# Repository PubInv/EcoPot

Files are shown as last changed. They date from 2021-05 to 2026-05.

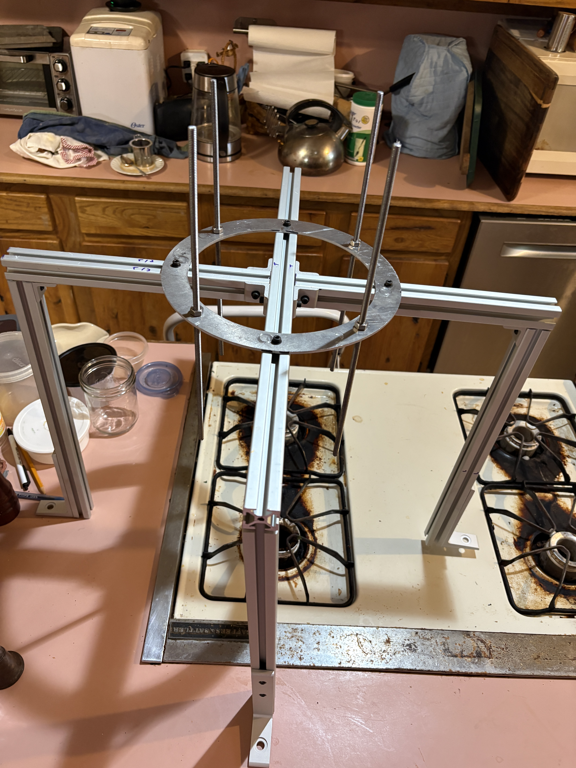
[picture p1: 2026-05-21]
doc/images/test_stand.jpg

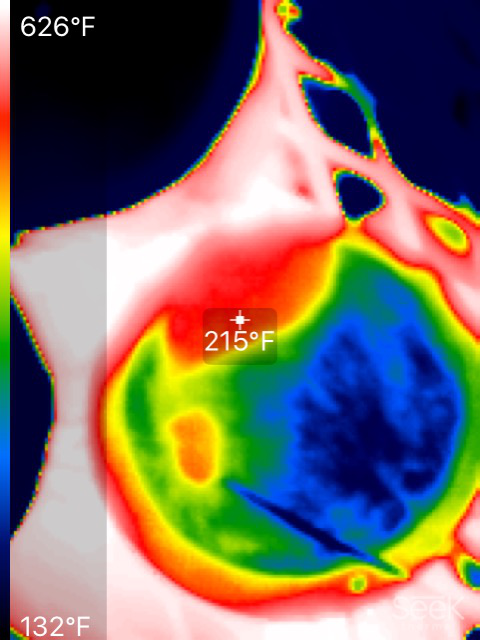
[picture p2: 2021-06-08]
Prototypes and Testing--Rice Team/IR Camera/First test (Open Flame)/IMG_0008.jpg

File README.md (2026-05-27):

# EcoPot
Project #5: A more efficient pot for those who cook over wood fires and related technologies

# Status - May 21st

Gialunuca Skirde had designed and built the a test stand, which we will use for simultaneously testing 4 pots for boiling time. Eventually, we will use this test frame to test over wood fires.

# The "Erlenmeyer" pot design - May 26th

We have not yet tested this pot design but just got it.





# Our Latest, Best Pot design...

These hemispherical, finned pots have been measured with a heat gun to be very efficient!
IMG_1574 (2)
IMG_1575 (2)

# Test with Mini Pot Holder In January

We have used Computational Fluid Dynamics (OpenFOAM) to simulate a number of designs.
Round-bottom parts are better than flat-bottomed pots. Heat transfer fins work.

It remains an open question if we can make a "wavy" pot or a pot like an "Erlenmeyer flask" which is better than our
best pot so far.

We also have a test apparatus for testing minuature 100 ml pots 3D printed in metal (see below).
Our next goal is to 3D print our best pots in metal and test them using this apparatus.






# Status as of September, 2025

We 3D-printed a pot without heat transfer fins in the 100ml size. Using a heat gun strapped
to a pipe, we were able to boil water efficiently. This is not a scientific test; it is a prelude
to A-B testing. Nonetheless, one must sometimes "play" to design the next step.



https://github.com/user-attachments/assets/eb1e9b2b-b452-4a84-bfa1-b5ce4db439bc

We attempted first to use a dryer hose, and that was a complete failure. The heat gun was so hot that 
it discolored the inside of the dryer hose. It is clear that a great deal of heat was lost through
the hose, as the discoloration faded for about 3 feet.



By the way, this small pot (we use 100ml standard test size) boils VERY quickly when put over a natural gas 
burner. We are learning that the temperature of the heating gas is extremely important.

# Status as of June, 2025

Thanks to Cledden Kwanin and Ivan Urdiales, we have a computational fluid dynaimcs (CFD) simulation
based on OpenFOAM. We are approaching the ability to test hypotheses with this tool.

We have a particular design based on an initial hypothesis: The faster the flow around the pot,
the more the flames and hot flue gases will be "sucked" against the pot due to the Coandă effect/Bernoulli 
effect. Based on this idea, we have made a "fish" shaped pot (and lid) which is streamlined,
with heat transfer fins. 

Our initial goal is to compare this pot to a cylindrical pot.






# Team Ecopot for Rice University

Team Ecopot, of Rice University, did the initial work based on ideas from Public Invention.
They are:

1. Christopher J Fang
1. Kaitlyn Wang
1. Stephanie A. Ponce
1. Concepcion C Appio-Riley
1. Sana A. Mohamed
1. Samuel Robedee

# Research Papers (WIP)







"Revisiting the optimal shape of cooling fins: A one-dimensional analytical study using optimality conditions" by
Joe Alexandersen and Ole Sigmund.

[https://arxiv.org/pdf/2012.04310](https://arxiv.org/pdf/2012.04310)

# Volunteer Opportunities

This project is still active, and the team is looking for additional volunteers with varied experience. Currently, the skillsets and experience that are needed include backgrounds in:

* Heat engineering
* Machining/making/3D printing
* Solid modeling/design

Alternatively, if you are new to the technical field but have interest in:

* Performing rigorous experiments, or
* Managing practical finances.

There is also a place for you on the team. If interested in joining the Ecopot or projects like it, reach out to Inventor Coach [Robert L. Read](read.robert@gmail.com) or Volunteer Coordinator [Miriam Castillo](https://www.linkedin.com/in/cstllgtrrz/). Ultimately, our mission is to further the reach of open-source medical engineering, and invent in the public, for the public. Check out our [Volunteer Page](https://www.pubinv.org/volunteer/) to learn more.

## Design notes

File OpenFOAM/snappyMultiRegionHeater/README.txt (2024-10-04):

- To solve the case, run the Allrun_Modified bash script for all the pre-processing. You can also use the Allrun-parallel or Allrun-serial bash scripts to run the case in parallel mode.
- Go to controldict in the system directory and adjust the endTime parameter to a higher (for more simulation time) or lower (for a shorter simulation time).
- Run chtMultiRegionFoam in the terminal afterwards to solve the case if you used the Allrun_Modified script. However, if you used the other scripts, run chtMultiRegionFoam -parallel
- Use touch "name.foam" to create a file with filename "name"(any name of your choice) with the extension ".foam" for ParaView.
- To clear all pre-processing and created time files, run the Allclean bash script.
- Open the created file (in this case name.foam) in ParaView and start viewing. On the bottom left side, turn of "internal mesh" under "Mesh Regions" to get a finer view.

- The 0/ field files contain nonsense patchFields.
  All interesting work is done using the changeDictionaryDicts.

- The solver uses region-specific decomposition for the heater.
  This can be useful when the solid region is relatively small and a
  normal decomposition would result in very few cells per process.

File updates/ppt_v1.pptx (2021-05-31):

## Ecopot

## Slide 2

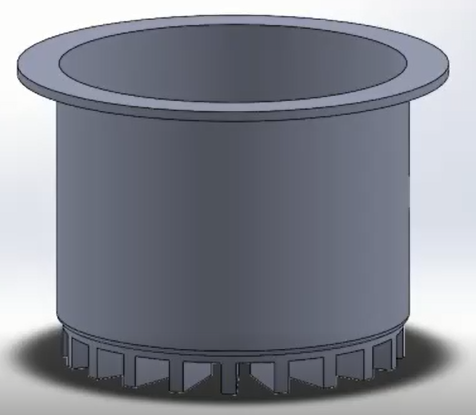
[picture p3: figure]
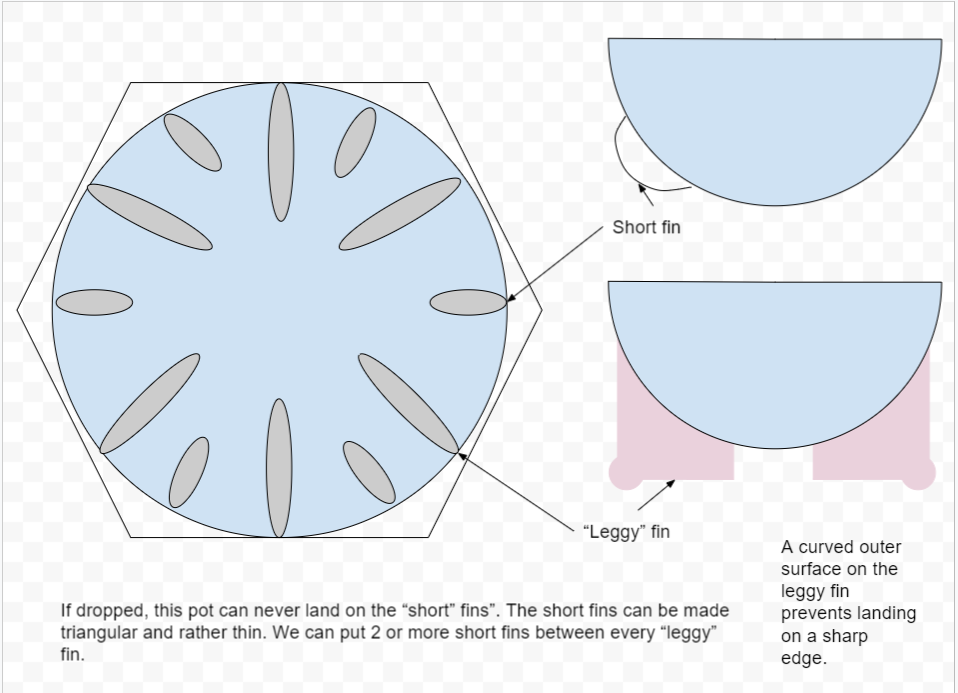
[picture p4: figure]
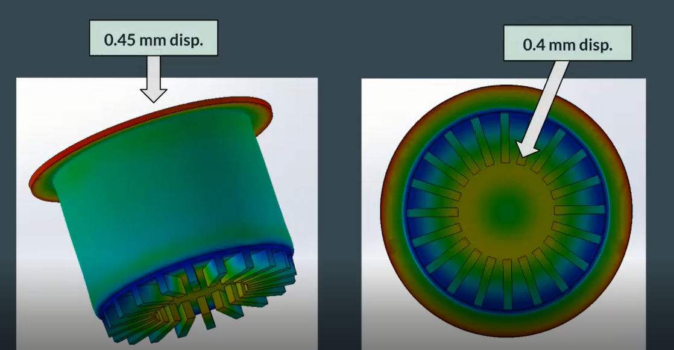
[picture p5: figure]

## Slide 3

1. Shape of fins
2. Arrangement of fins
3. Top of the pot/handles
4. Heat transfer within the pot – primary and secondary air inlet
5. Uniform heating at the bottom of the pot

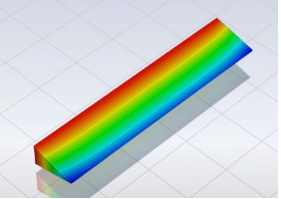
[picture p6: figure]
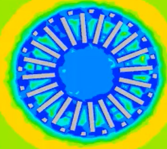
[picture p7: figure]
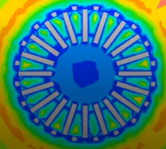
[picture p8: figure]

3

1

2

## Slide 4

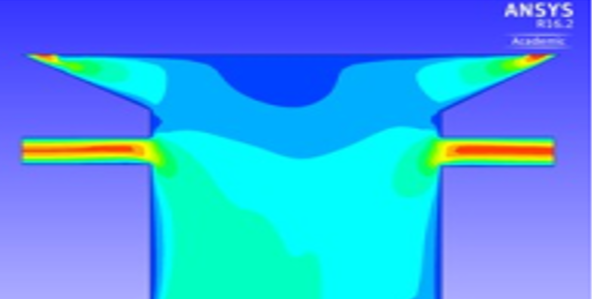
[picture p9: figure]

4- Modifying the pot design to prevent excess pressure buildup within the pot

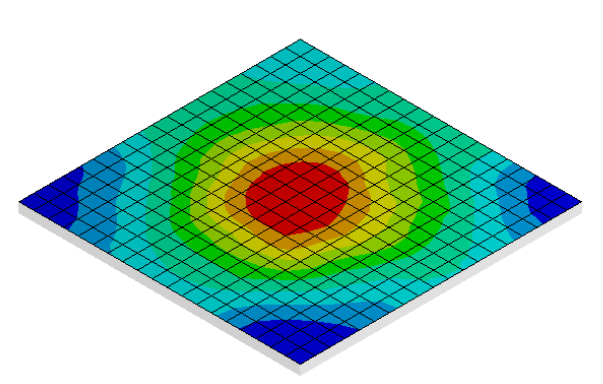
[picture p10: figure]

5

## To do….

1) Fin arrangement + theory
2) Lid of the pot
3) OpenSCAD

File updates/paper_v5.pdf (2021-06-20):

# Energy efficient cooking pot- Ecopot

add all team members

May 2021

## 1 Introduction

Ecopot is an attempt to make a more fuel-efficient cooking pot for the one billion people who cook on wood gathered by hand from the ground. Making a pot which requires less firewood would decrease the world carbon footprint, but more importantly would save many people, often women, hours of tedious labor and may help reduce gender inequity.
ADD A LITTLE MORE INFO

1

## 2 Choosing the right fin shape

Convective heat transfer between a surface and the surrounding has been a major issue and a topic of study for a long time. In this project, the heat transfer performance of fin is analyzed using ANSYS workbench for the design of fin with various design configuration such as cylindrical configuration, square configuration and rectangular configuration. The heat transfer performance of fin with same base temperature having various geometries is compared. In this thermal analysis, Aluminum was used as the base metal for the fin material and for various configurations. Fin of various configuration are designed with the help of Solidworks and analysis of fin performance is done through ANSYS Fluent.

The Fin is a major component used in many systems for increasing the rate of heat transfer. By doing thermal analysis on the fins, it is helpful to know the heat dissipation and rate of heat transfer in different types of fins. Increasing the temperature difference between the fin configuration, slightly increasing the convection heat transfer coefficient or slightly increasing the surface area of the fin increases the heat transfer. Sometimes it is not economical or it is not feasible to change the first two options. Therefore we try to compare the performance of fins by changing the surface area i.e the shape of the fins.

2

### 2.1 Simulation parameters

1. Rectangular fin: Volume = 4X10⁻⁵m³

, Area = 4X10⁻⁴m²
, Mesh - Fine
mesh, Model - Energy (ON), Viscous k-epsilon (Realizable), Boundary conditions - Inlet velocity of 5 m/s, heat transfer coefficient = 210 W/m-K (Aluminum), Solution method - SIMPLE algorithm, Initialisation - Standard, Number of iterations - 500
2. Circular fin: Volume = 4.15X10⁻⁵m³

, Area = 4.15X10⁻⁴m²
, Mesh -
Fine mesh, Model - Energy (ON), Viscous k-epsilon (Realizable), Boundary conditions - Inlet velocity of 5 m/s, heat transfer coefficient = 210 W/m-K (Aluminum), Solution method - SIMPLE algorithm, Initialisation - Standard, Number of iterations - 500
3. Triangular fin: Volume = 2X10⁻⁵m³

, Area = 2X10⁻⁴m²
, Mesh - Fine
mesh, Model - Energy (ON), Viscous k-epsilon (Realizable), Boundary conditions - Inlet velocity of 5 m/s, heat transfer coefficient = 210 W/m-K (Aluminum), Solution method - SIMPLE algorithm, Initialisation - Standard, Number of iterations - 500

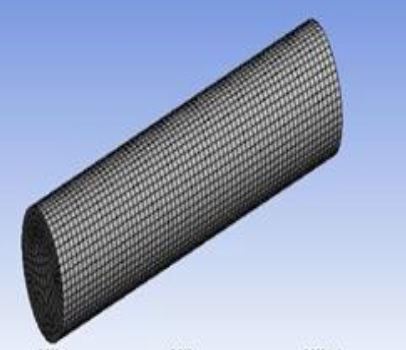
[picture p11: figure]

Figure 1: Meshed circular fine

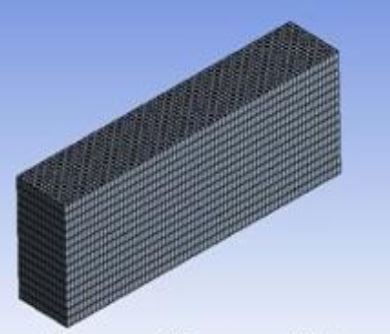
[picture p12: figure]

Figure 2: Meshed rectangular fine

3

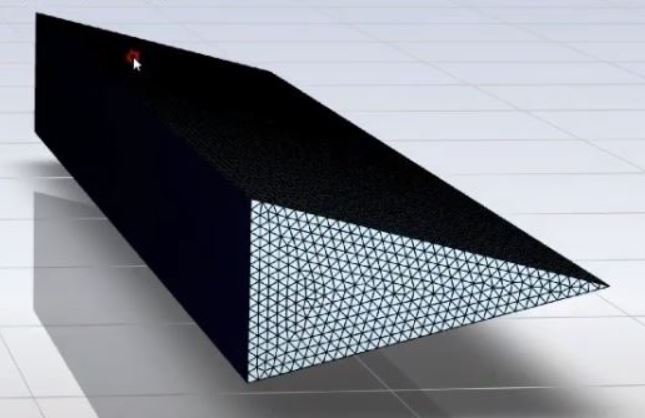
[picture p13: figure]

Figure 3: Meshed triangular fine

Simulations were performed for 500 iterations and convergence was observed around 400 iterations.

### 2.2 Simulation results

The results of the simulation along with the colorscale is shown below. The base temperature of the fin was initialised to 380 K (100 °C). The following assumptions were used for the simulation:

- Steady state
- Constant material properties (independent of temperature)
- No internal heat generation
- One-dimensional conduction
- Uniform cross-sectional area
- Uniform convection across the surface area

Figure 4: Heat transfer colorscale

4

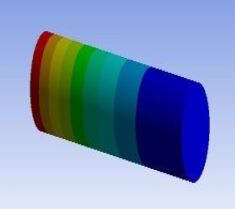
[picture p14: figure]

Figure 5: Heat transfer across circular fin

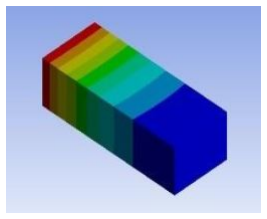
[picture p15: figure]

Figure 6: Heat transfer across rectangular fin

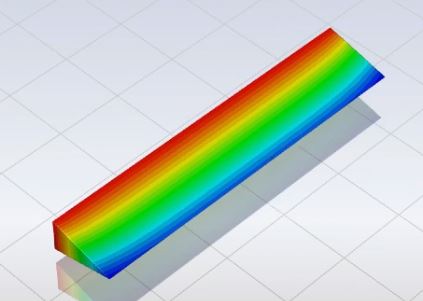
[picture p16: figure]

Figure 7: Heat transfer across triangular fin

5

### 2.3 Conclusion

The use of fins (extended surface), provide efficient heat transfer. Heat transfer through fin of triangular configuration is higher than that of other fin configurations. Temperature at the end of fin with triangular configuration is minimum, as compare to fins with other types of configurations. The effectiveness (defined as the ratio of the actual heat transfer that takes place from the fin to the heat that would be dissipated from the same surface area without fin) of fin with triangular configuration is also greater than other configurations. Choosing the optimum sized fin of triangular configuration will reduce the cost for heat transfer process and also increase the rate of heat transfer.

6

## 3 Designing the top of the pot

As per multiple field surveys, people prefer pots having a rounded top to latch onto rather than having separate handles attached to the top. This requires changing the design of the pot at the top and studying the heat transfer around that region.

### 3.1 Simulation parameters

Mesh - Fine mesh, Model - Energy (ON), Viscous k-epsilon (Realizable) with Enhanced wall treatment, Boundary conditions- Pressure based, Absolute, Time-Steady, 2D Planar, Wall - No slip, Solution method - SIMPLE algorithm, Initialisation - Standard, Number of iterations - 500

### 3.2 Simulation results

### 3.2.1 Simple extended top

Figure 8: Temperature contour at the top of the pot, iteration number 100

Figure 9: Temperature contour at the top of the pot, iteration number 300

Figure 10: Temperature contour at the top of the pot, iteration number 500

7

### 3.2.2 Extended top with a rounded edge

Figure 11: Temperature contour at the top of the pot, iteration number 100

Figure 12: Temperature contour at the top of the pot, iteration number 300

Figure 13: Temperature contour at the top of the pot, iteration number 500

The colorscale is same as the scale used in section 2.2.

### 3.3 Conclusion

By comparing the temperature contours, we find that the top with rounded edges has a more uniform heat transfer rate across the profile and hence would lead to faster heating time. Also, since more heat is lost along the sides of the top, covering it using a suitable cover would improve the efficiency further. However, making a rounded edge would increase the production time as it would be a two step process - making a simple extended top and then flattening the sides. However, this is a trade off that’s worth making since it would lead to a more efficient pot.

8

## 4 Effect of fin configuration on turbulent natural convective heat transfer

We wish to study the difference in heat transferred due to different arrangement of fins radially. Effect of fin height on flow and temperature fields has been studied for different fin arrangements. Rahnama and Farhadi [5] reported this effect on turbulent natural convection for the case of horizontal fin arrangements. The streamline pattern obtained showed that increasing fin height to radius difference ratio more than 0.4 results in two recirculation zones.

The arrangements tested includes two fins in horizontal and two fins in vertical direction and also the same fins rotate 45 degrees relative to horizontal and vertical arrangement. Flow and temperature fields in the form of streamline and isotherm are shown superimposed. There are differences between the streamline and temperature contours for different configurations.

Buoyancy-induced motion in the lower part of the annulus is very weak due to the fact that high temperature surface (inner cylinder surface) is over the low temperature one (outer cylinder surface). So there is a stable density stratification which resists to fluid flow. In fact, there is a very weak fluid motion in the lower part of the annulus.

The fluid flow being started to circulate in the upper part of annulus, may have enough momentum to continue its motion to the lower part. The fluid along the inner cylinder tends to move away from the symmetry line and tries to bend downward upon meeting the first fin. However, the buoyancy force created by heating of air prevents air from moving downward and thus creates a region of almost stagnant flow in the bottom of the annulus.It should be mentioned that increasing the number of fins makes the number of recirculation regions to increase.

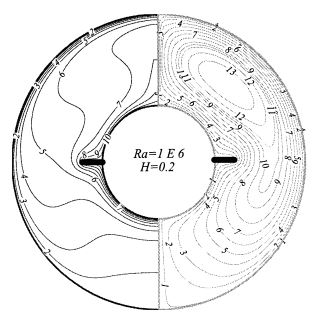
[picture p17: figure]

Figure 14: Isotherms for 2 fin arrangement

9

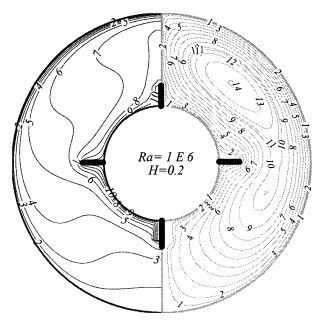
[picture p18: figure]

Figure 15: Isotherms for 4 fin arrangement, θ = 90◦

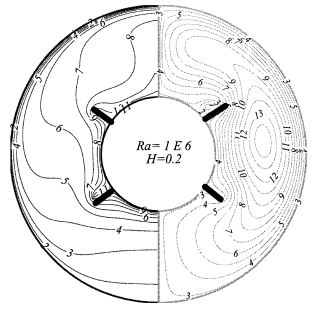
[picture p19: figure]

Figure 16: Isotherms for 4 fin arrangement, θ = 45◦

### 4.1 Nusselt Number

The Nusselt number (Nu) is the ratio of convective to conductive heat transfer at a boundary in a fluid. Convection includes both advection (fluid motion) and diffusion (conduction). The conductive component is measured under the same conditions as the convective but for a hypothetically motionless fluid.

Nu = Ri

ln(R).

∂T
∂r
where the last term represents the temperature gradient in radial direction.The mean Nusselt number is obtained by integrating the local Nusselt number over the inner cylinder and fin surfaces.

10

Figure shows variation of mean Nusselt number ratio for the case of two fin arrangements with ratio of fin height to radius difference.

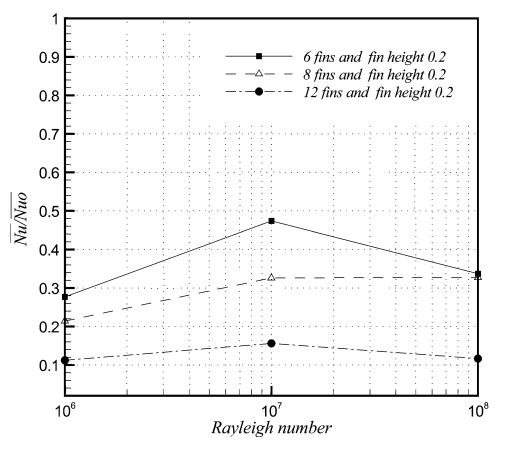
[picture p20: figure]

Figure 17: Variation of Nusselt number for different fin arrangements

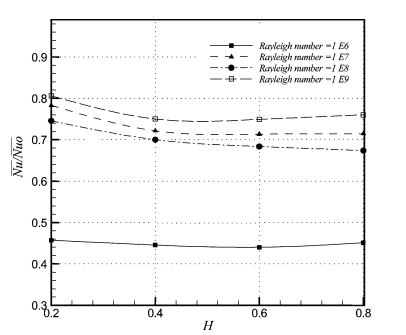
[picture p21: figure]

Figure 18: Variation of Nusselt number with Rayleigh number

### 4.2 Conclusion

The following conclusions can be drawn from the fin arrangement study:

1) For all configurations, results indicate that local Nusselt number increases with an increase in Rayleigh number. Increasing the number of fins increases mean Nusselt number ratio, with in turn increases heat transfer rate.
3) Higher fin height has some effect on fluid motion. If there is a tendency toward reducing heat transfer rate between two concentric horizontal cylinders, it is better to use higher fin height.

11

4) Fin arrangement has no significant effect on mean Nusselt number prediction although its effect on flow and temperature fields is remarkable for the case of four fin arrangement.
5) There is a possibility that alternating shorter and longer fins (of different heights) may increase the heat transfer rate due to an increase in the number of recirculation zones.

12

## 5 Studying the flow of air around the pot

We try a CFD approach for modelling of combustion in a cooking stove and study the flow of air around the stove. The stove has a cylindrical structure made of aluminium and is covered with an aluminium plate to model airflow. The combustion phenomena inside the stove is modeled using the Eddy-breakup combustion model and the k- turbulence model.The flow considered, is due to the buoyancy effect and the spatial variation of species concentrations. Empirical data of a typical cook stove has been used as boundary conditions.

### 5.1 Boundary conditions

Conservation equations are solved by the numerical methods in which the boundary conditions will be the preparatory points of the equations. It is important to take the right boundary conditions that are most appropriate to the practical problem. There are three types of boundary conditions have been used for the simulations while getting a practical in- touch with the cook stove problem. The list of boundary conditions used are mentioned below.

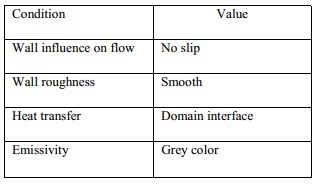
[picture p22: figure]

Figure 19: Boundary conditions for airflow simulation

Computational domain and the physics of the simulation were built on the builder of the CFX-5.6. The conservation equations were discretized using the finite volume method in the solver. The SIMPLEC algorithm achieved velocity and the pressure relation. The total time duration for the simulation was 16 hrs 33 minutes.The results of the simulation are shown below.

To study the shape of airflow at the top, temperature and velocity data from the simulation region was dumped to an external file and was separately plotted using MATLAB. The velocity and temperature contours are shown below.

13

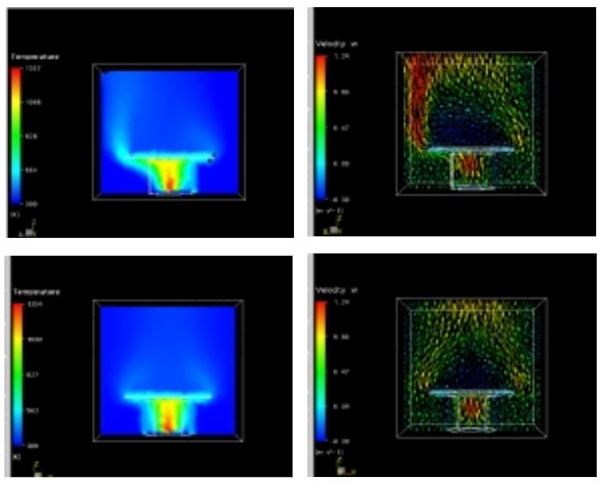
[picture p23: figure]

Figure 20: Temperature contours and velocity vectors of airflow around the pot

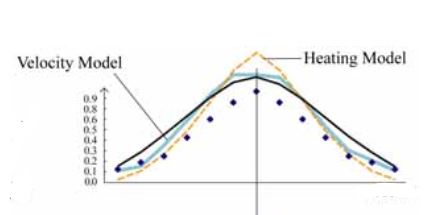
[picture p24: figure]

Figure 21: Plot of velocity vectors at the top of the pot

### 5.2 Conclusion

The following conclusions can be drawn from the airflow study:

1) Although the flow of air appears to take a hemispherical shape, the simulation eventually converges and a conical shape is seen above the pot.
2) The conical shape has been suspected to be formed due to the aerodynamics of the flow. When flow separates after travelling along the edges, the streams seems to undergo a separation and the two streams converge some region above the pot.
3) Fig 21 clearly shows the flow to be following an approach similar to flow around a moving aerodynamic vehicle. Hence if the shape of the pot lid is made similar to a cone, this would lead to air moving along the lid and result in maximum heat transfer.

14

## 6 CFD Analysis of a hemispherical cooking pot

We aim to analyse the double walled cooking unit under different geometry and flow conditions by using the CFD tool FLUENT 6.2. This study gives significant insights that will provide the direction for improvement in energy efficient cooking.
The model is created using Pro-E software and this model is meshed with a tetrahedral element, using hypermesh software. This meshed model is exported to the Fluent software for analysis.The following assumptions are made for the CFD analysis:
1) The density, specific heat and thermal conductivity are considered to be constant for the fluid in the pot
2) The outer surface of the cooking unit is perfectly insulated, and hence, the heat flux is considered as zero.

### 6.1 Boundary conditions

Velocity inlet (specified normal to the boundary, 0.5 to 2.5 m/s with increments of 0.5m/s), temperature (constant, applied to grid cells where back flow occurs), wall boundary condition with specified food side heat transfer coefficient and free stream temperature (no heat flux on the outside), food side heat transfer coefficient (50,60,2000 W/m²
-K). This large variation in heat transfer coefficient is considered due to various heat transfer mechanisms involved during any cooking process like free convection, stirring of the food stuff in the cooking unit, heat transfer due to nucleate boiling and evaporation, which has large variations in the heat transfer coefficient.
A separate Grid independence study was carried out for optimizing the mesh size and cell count. Fig. 13 shows the variation in the heat transfer rate with respect to the mesh count employed in the analysis. It was observed from the figure that after a mesh count of 520,000 tetrahedral elements, the variation in the heat transfer rate from the inner surface of the vessel was consistent. Hence, a standard mesh count of approximately 520,000 tetrahedral elements with a size of 2.4 mm was used for the final analysis, for all the vessel configurations. The Fluent software employs the finite volume method for solving the mass, momentum and energy conservation equations. The fully implicit method is adopted with the SIMPLE algorithm as the solver option for the steady flow simulation, and the second order upwind scheme was used for solving all the conservation and turbulence equations.

15

### 6.2 Simulation and results

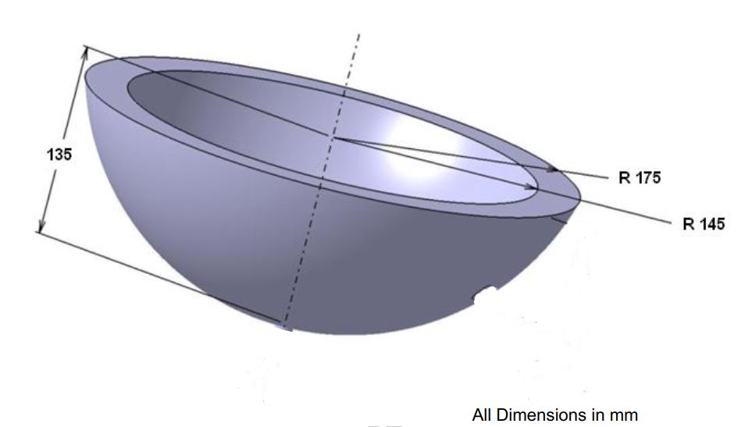
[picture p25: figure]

Figure 22: Model of a thin walled hemispherical pot

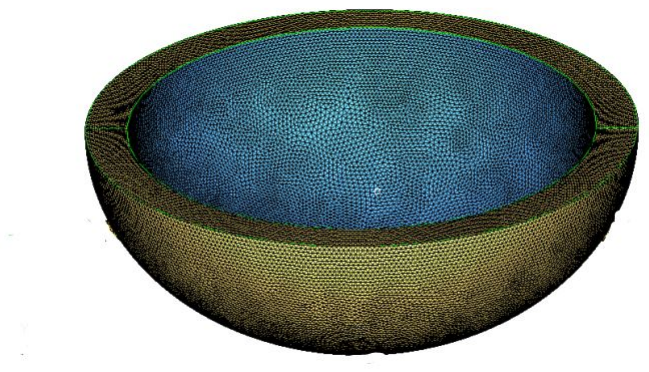
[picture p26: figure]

Figure 23: Meshed model of a thin walled hemispherical pot


Figure 24: Finding the suitable mesh size

16


Figure 25: Temperature contour at 200 iterations


Figure 26: Temperature contour at 500 iterations


Figure 27: Temperature distribution within the wall

17


Figure 28: Temperature distribution of food within the pot


Figure 29: Heat transfer curve; triangle, square - heat transfer rate, different turbulent models, circle - temperature of water within the pot

From the simulation analysis performed at various surface heat transfer coefficient at the food side, it is inferred that the increase in the food side heat transfer coefficient (ho) plays a major role at the lower range of ho values, to increase the surface heat flux. However, at the higher range of ho values, the effect of the increase in the surface heat flux is insignificant.

18

## 7 References

[1] Knight RW, Goodling JS, Hall DJ. Optimal thermal design of forced convection heat sinks – analytical. J Electron Packag. 1991;113:313–321.
[2] Incropera FP, DeWitt DP. Fundamentals of Heat and Mass Transfer. New York: Wiley; 1990.

[3]Kundu B. A closed form solution for ac electro-kinetic driven flow in a microchannel. J Therm Eng. 2015;1:289–294.

[4]Mirapalli S, Kishore PS. Heat transfer analysis on a triangular fin. Int J Eng Trends Technol.. 2015;19:279–284.
[5] M. Rahnama, M. Farhadi, Effect of fin height on turbulent natural convection heat transfer in a horizontal annulus, in: The 13th International Symposium on Transport Phenomena, Victoria, BC, 2002, pp. 345–350.

19

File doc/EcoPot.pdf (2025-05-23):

# DRAFT

# EcoPot: A More Efficient Pot for Wood Fires

1

st Robert L. Read Public Invention Austin, TX, USA
ORCID: 0000-0003-4749-7045 email: read.robert@gmail.com

2

ndCledden Obeng-Poku Kwanin 3ndIvan Urdiales

4

thAditya Choksi

May 23, 2025

Abstract

One billion people cook daily on open fires with hand-gathered firewood. A more efficient cooking pot would save firewood, saving them time. Using the OpenFOAM computational fluid dynamics system, we have evaluated different pot designs seeking a more efficient pot. We expect gathered-wood fires to be cooler and more turbulent than gas fires, and to transfer heat more through conduction than smoldering coal fires. We hypothesize that a pot which encourages smooth, fast flow of the hot ”flue” gases around the pot will maximize heat transfer on gathered-wood fires. In particular, we have compared a rounded-bottom pot with heat conduction fins to a simple cylindrical pot.

## 1 Introduction

In 2025, about one billion people cook on wood gathered from the ground or cut by hand. Often this wood is not seasoned (dried), causing the fire to inefficiently waste heat vaporizing the moisture content.
Cooking varies widely based on available ingredients, technology, and custom. One of the main ways of cooking is to cooking something relatively moist in pot. This is generally a grain-based porridge (rice, maise, barley, quinoa, millet, wheat, oats) or some kind or a ”stew” of starchy vegetables such as potatoes or cassava. Sometimes legumes (beans and peas) are cooked, and sometimes fruit or meat products or eggs are also added. Of course, sometimes food is baked (bread), or grilled or roasted. However, it seems that world-wide a majority of calories consumed by people are in the form of starches cooked in moist conditions. Increasing the efficiency of this kind of cooking therefore is mostly likely to benefit the most people by saving them the labor and cost of gathering fuel.

1

# DRAFT

Often this cooking is done on a ”three stone fire” with a pot propped on stones above the fire. Sometimes a metal grill or grate is available, but sometimes not.

### 1.1 Motivation

### 1.2 Cultural Considerations

Some cultures may have traditional pots, which are essential to some traditional, culturally significant dishes. However, our approach is to make as utilitarian a pot as possible for making the most common fare, rather than foods cooked for feasts and special occasions.
However, cleanability and handles remain an important consideration.

## 2 Related Research

## 3 Some Hypotheses

This research is designed to test several hypotheses:

1. Pot design can greatly effect the fuel usage of a pot.
2. A pot design which makes the flue gases move quickly against the pot in a smooth flow is more efficient than a pot that does not support a smooth, fast flow.
3. Rounded (hemispherical) pots will be more efficient for cooking than cylindrical pots.
4. The efficiency of a pot will be enhanced with heat transfer fins.

We emphasize that these are untested hypotheses which may be false. However, they are supported by they following reasoning:

1. Ancient people seem to have preferred round-bottomed pots for cooking, and flat-bottomed pots of food storage. This is particular evident in the Museum of Athens, which displays a wide variety of bronze cooking and storage vessels, consistently labeling the round-bottomed ones as cooking pots and the flat-bottomed ones as storage pots.
2. If the flow around a pot is fast, the flue gases will be entrained against the pot by the Bernoulli/Coanda effect. Because the flow total, this may cause the flames of a yellow-flamed gathered-wood fire to be ”held” against the pot, which will increase both conductive and radiative heat transfer. A stagnant flow would be expect to ”insulate” the pot. Heat transfer is always a function of time, so it may be that fast-flowing gases will leave the vicinity of the pot too quicly, still hot and before they have transferred all of their heat. Nonetheless, a slower flow may be even worse, in that it

2

# DRAFT

may force hot gases away from the pot, prevenint efficient heat transfer all together!

3. Rounded (hemispherical) pots will be more efficient for cooking than cylindrical pots.
4. Preliminary tests on a real pots on hydrocarbon fueled fires performed by our collaborators at Rice University found a 42% decrease in boil time with a pot with radiative fins. Modern gas fuel camping stoves, such as the JetBoil, use heat transfer fins.

### 3.1 Why Not Consider Stoves and Skirts?

It is entirely possible that the best way to efficiently cook with gathered wood is use an iron stove, what in American English is often called a wood-burning stove. Some engineers have suggested that a pot skirt, a metal device which partially encloses a pot, might also make cooking more efficient.
We are intentionally not investigating these ideas because we believe much can be learned by considering the simpler problem of trying to design a more efficient pot. If we can develop the ability to design, simulate via CFD, and ultimately test on real gathered wood fires, this technical capacity will no dout allow us to conduct research on more complicated cooking equipment.

### 3.2 Why Not Consider Cost?

Premature optimization is the root of all evil.

Donald Knuth

Similarly, we currently give no consideration to the cost of manufacturing a pot of a particular design. Pots 3D printed in metal are so expensive that there economic use for many people is completely precluded. However, we believe that any design which is drastically more fuel-efficient than a standard pot will be mass-producible at such scale that we not consider the cost of manufacture at this early stage of research.

## 4 Efficiency

Defining the efficiency of a cooking pot is a matter of practical engineering, not science. The authors have invested the basic amount of fuel required under ideal conditions which could only be obtained with expensive equipment in a laboratory. For example, using pure carbon as a fuel and pure O2 as an oxidant, and operating under pressure inside the cooking pot itself, it would take only 27.15 grams of carbon to cook 12 cups of rice.[1] It is interesting to posit such efficiency as an absolute chemical limit, but it is completely impractical.

3

# DRAFT

More practical is define efficiency in purely relative sense. Define a ”standard pot” to be a roughly cylindrical pot (with slightly outward sloping side) that can safely contain 3 liters of water. Since fires vary so much by fuel quality, outside wind, and even the skill of the person tending the fire, we will define efficiency relative to a giving cooking context C. Let F(C, S) be the mass of fuel in grams required to bring 3 liters of water to boil in a cooking context C in a standard pot S. The for a new pot design D the relative efficiency for a given context is F(C, S)/F(C, D). A higher efficiency is better.
This definition does not include the ability of the pot to keep food warm when it is taken off the fire, which may be an important practical decision.

### 4.1 Defining Efficiency

The easiest to manage definition of efficiency a relative definition.

### 4.2 A note on absolute efficiency

### 4.3 Testing Strategy

Our basic strategy was to design small, 100ml “mini-pots” with a CAD program to be tested with ANSYS simulation software and to order small, affordable 3D printed steel pots based on these designs. The small tests could be tested relatively easily with simple test apparatuses.

## 5 Initial Test Plan

In order to test the hypotheses presented in the paper, we design pots using OpenSCAD free, fully-parametric CAD program. An experienced OpenSCAD designer will understand how to produce exportable model files without main OpenSCAD script called ParameterizedPotDesigns.scad[2]. This produces 3D models which can be imported into a CFD simulation program (OpenFOAM) or 3D printed for real testing.
Taking advantage of the fully parametric capability of OpenSCAD, we developed the OpenSCAD script so that we can produce pots in any volume, and can select a variety of features. In general, the fuel efficiency of a pot can only be measured against another pot of different design with the same capacity. Initially we intend to begin testing with pot designs, which can be selected with the ”ptype” parameter in the OpenSCAD file:
1. flatbottom
2. roundbottomwithf insandhandles
We have also developed a variety of lids.
Our initial plan is to test Hypothesis 1 by simulating these two pots in OpenFOAM.

4

# DRAFT

## 6 OpenFOAM Simulations

Our basic simulation approach is to use OpenFOAM. A pot design is placed in side a cube, which has an updraft of hot air. The OpenFOAM CFD models the transfer of heat from the air to the pot. Each pot has a ”contents” which represents the water, modeled as a fixed block shaped like the interior of the pot, but having water-like properties set in OpenFOAM.
The initial approach is very unlike a fire in some ways:
1. It does not include turbulence
2. It is uniformly warm across the entire space, whereas a fire is likely hottest near its center.
3. It does not model radiative heat transfer, which is likely significant.
4. Flue gases may contain a significant amount of CO2 and H2O vapor, which may have different heat transfer properties than air.

Our basic test methodology will be to compare two pot designs, one considered a control (S) and a design (D) in OpenFOAM in the same simulation hot-gased environment. We will run the simulation long enough that each has reached 95C in temperature (because we cannot model the vaporization of our contents easily.) We will then use the time for the contents of each pot to reach 95C from 25C as a stand-in for consumed fuel, and compute the relative efficiency of the new design as Tc/Ts.

## 7 Mini-pot Test Methodology

Mini-pots were tested for boil time over the burner of a stove using a standard clamp apparatus.
We also constructed a cardboard profile sheet and attempted to do IR imaging on this sheet to verify our understanding of the fluid flow and heat transfer [More needed here.]

### 7.1 Mini-pot Test Data

## 8 Constructing large pots

Based on the relative success of the min-pots, large, 12-cup pots were constructed and tested over propane burners.

### 8.1 Large Pot Test Data

## 9 Rounded Bottom Designs

Later the team designed a pot using the successful half-radial approach that had a rounded (hemispherical) bottom. The theory was that the Coanda effect would

5

# DRAFT

keep the hot gases in contact with the pot. Both Ansys simulation and mini-pot flame testing suggested this is actually true. There is some reason to believe the rounded-bottom pots may be a more efficient point in the design space than flat-bottomed pots, although they may be more difficult to manufacture.

## 10 Acknowledgments

A Senior capstone engineering team named Team EcoPot at Rice University in 2021 did some initial CFD simulation in Ansys Fluent and tested very small pots. They included Stephanie Ponce, Christopher Fang, San Robedee, Chinwe, Kaitlyn, and Sana.

## 11 Conclusions

This work demonstrates that pots with heat-exchanging fins can be more efficient than standard pots in some way. If this translates to decreased fuel consumption without inordinate additional expense or loss of durability, these pots may ease fuel gathering burdens, cook faster, and create less pollution than standard pots.

## References

[1] Basic Chemistry of Sealed Combustion, 2025. [Online; accessed 25-May-2025].
[2] Parameterized Pot Designs, 2025. [Online; accessed 25-May-2025].

6

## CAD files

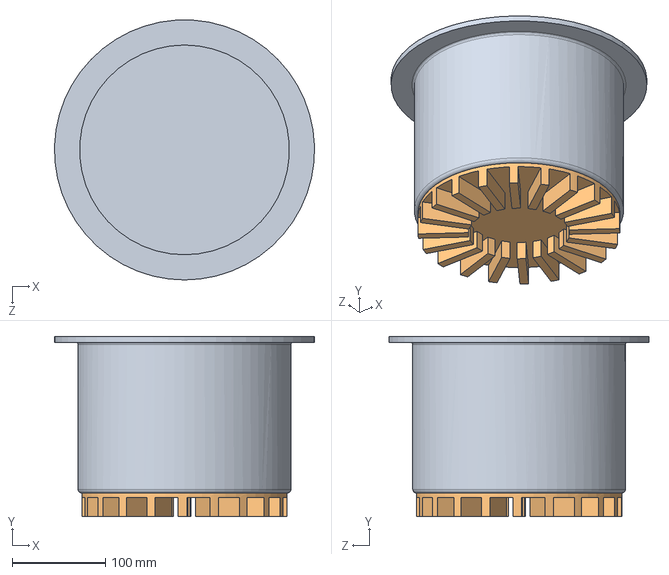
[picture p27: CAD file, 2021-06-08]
Prototypes and Testing--Rice Team/Models _ Simulations/Solidworks Drop Tests/Final Ecopot Assem.SLDASM
279.3 x 193.7 x 279.1 mm
Life Sized Half Radial Pot_Scaled Fins
Finned Heat Sink

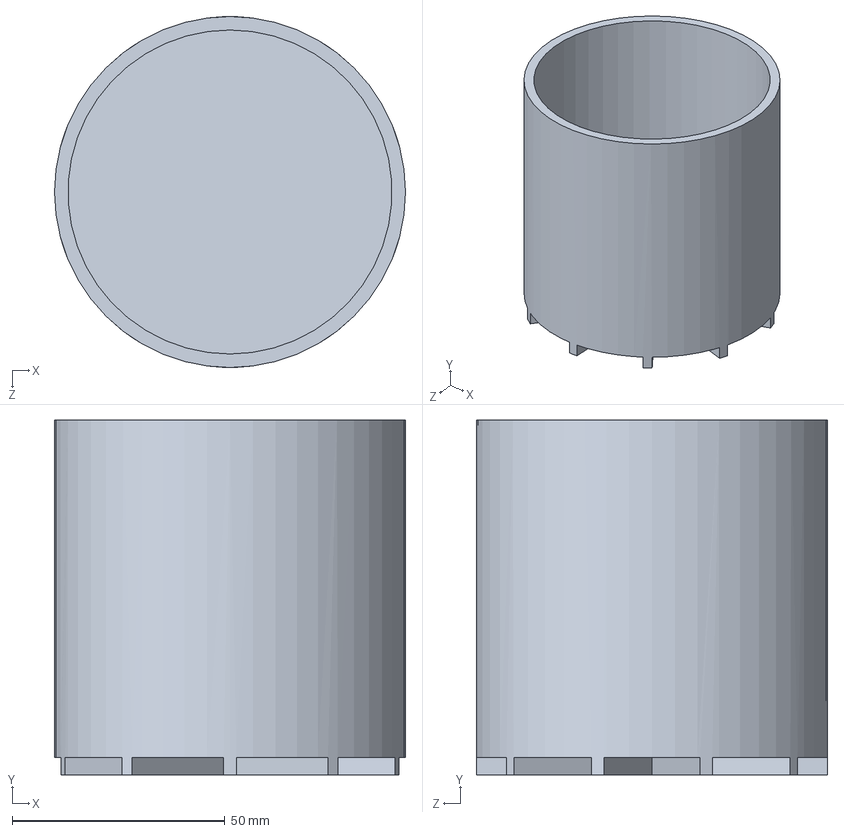
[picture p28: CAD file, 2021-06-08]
Prototypes and Testing--Rice Team/Models _ Simulations/Generation 2 Models - 2 Inch Finned Shapeways Models /Radial Full Finned Pot.SLDPRT
82.5 x 83.4 x 82.5 mm

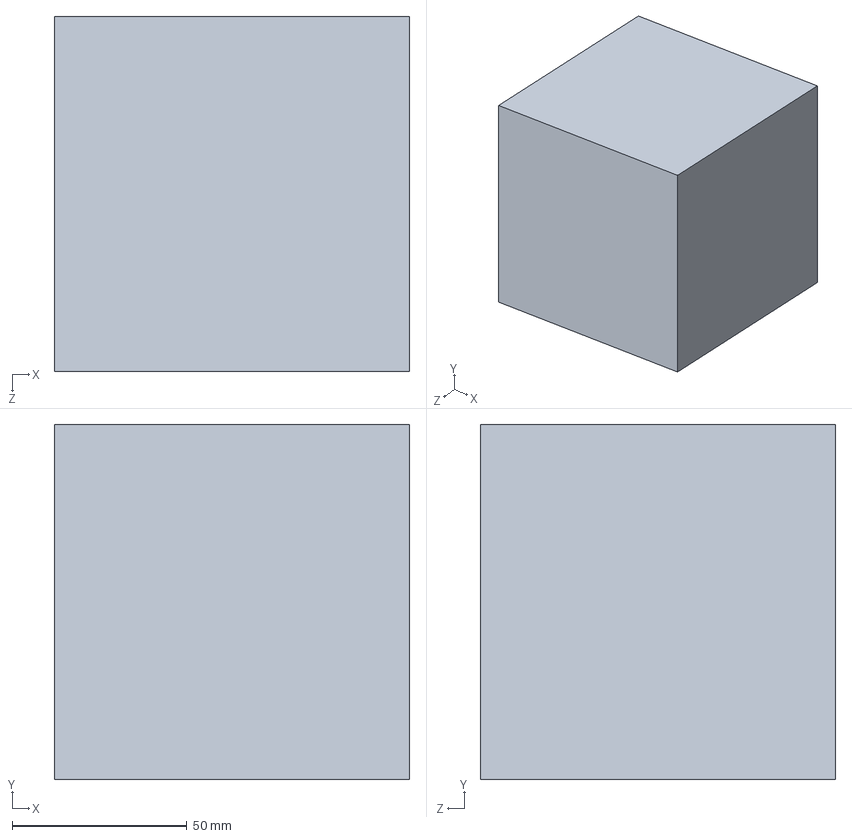
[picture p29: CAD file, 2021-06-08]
Prototypes and Testing--Rice Team/Models _ Simulations/Generation 3 Models - Half Radial Fin Iterations + Fin Guard Models/Fullguard Assembly.SLDPRT
101.6 x 101.6 x 101.6 mm

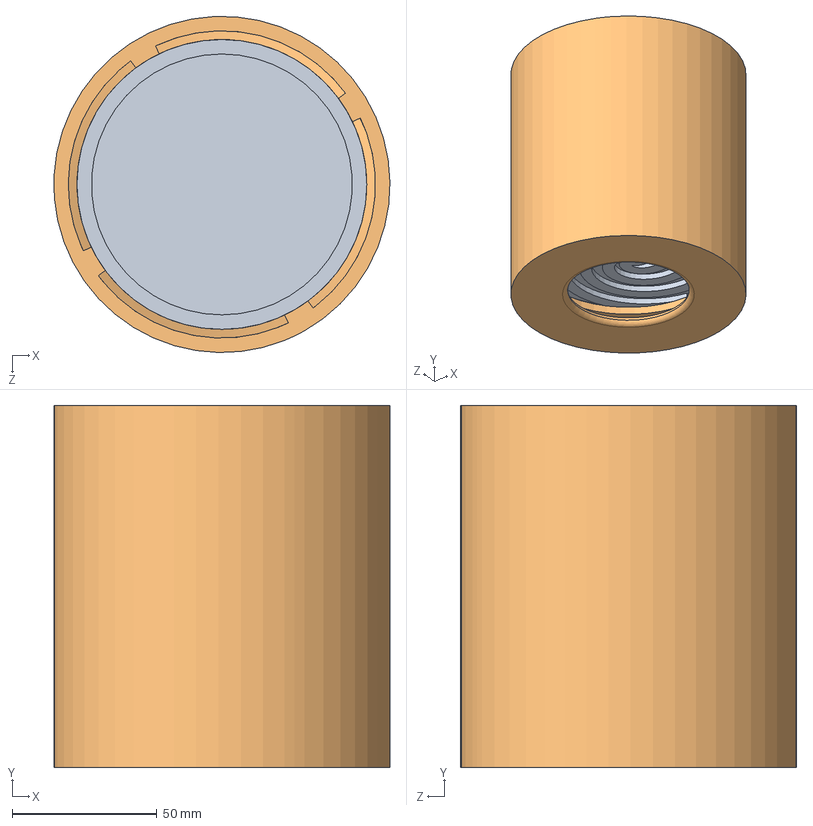
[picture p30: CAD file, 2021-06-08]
Prototypes and Testing--Rice Team/Models _ Simulations/Generation 1 Models - Concept Ideation and Creation/Helical Vane Pot v2.SLDASM
115.9 x 125.0 x 115.9 mm
Helical Vane Inner Pot v2
Helical Vane Outer Pot v2

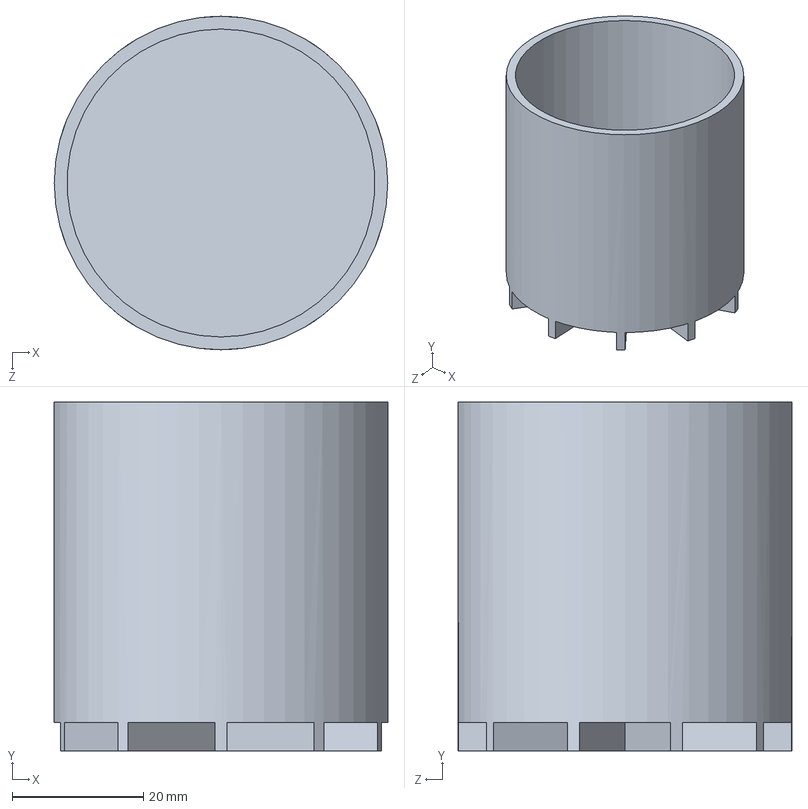
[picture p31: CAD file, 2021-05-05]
Prototypes and Testing--Rice Team/Models _ Simulations/Generation 2 Models - 2 Inch Finned Shapeways Models /Radial Full Finned Pot 2 Inch.SLDPRT
50.8 x 53.2 x 50.8 mm

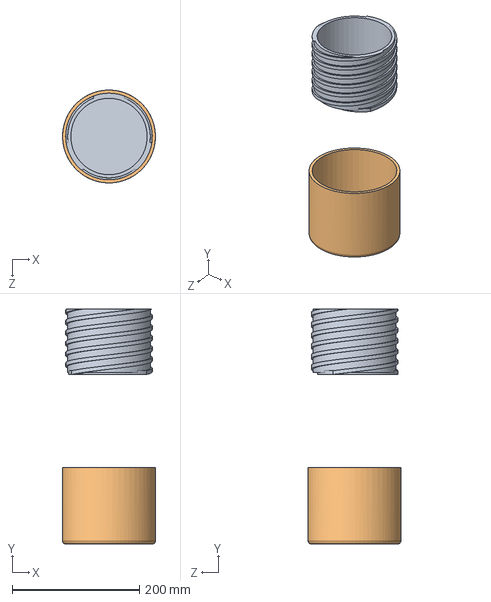
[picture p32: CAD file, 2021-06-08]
Prototypes and Testing--Rice Team/Models _ Simulations/Generation 1 Models - Concept Ideation and Creation/Helical Vane Pot.SLDASM
146.0 x 369.3 x 145.9 mm
Helical Vane Inner Pot
Helical Vane Outer Pot

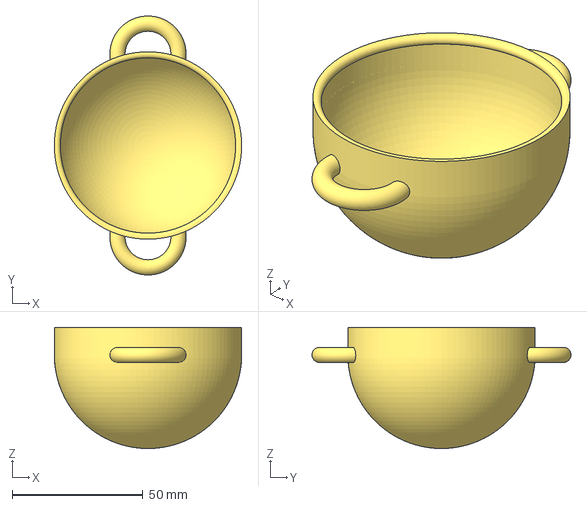
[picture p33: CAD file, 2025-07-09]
hypo-Round_vs_Flat/ParameterizedPotDesigns_Cledden_09-07-25.RobThinned.3mf
71.7 x 99.1 x 46.3 mm

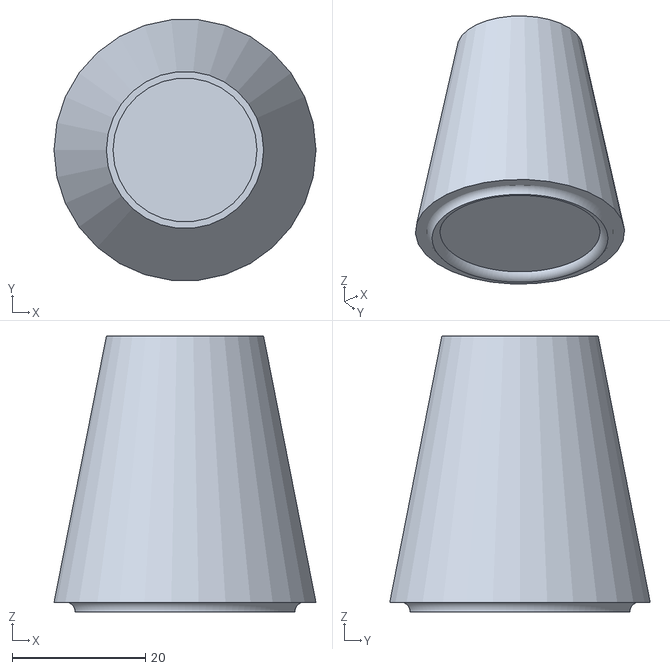
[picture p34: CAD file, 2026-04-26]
OpenFOAM/erlenmeyer_pot_16605mm_wall_thickness/constant/geometry/conicalLid.stl
39.3 x 39.1 x 41.4

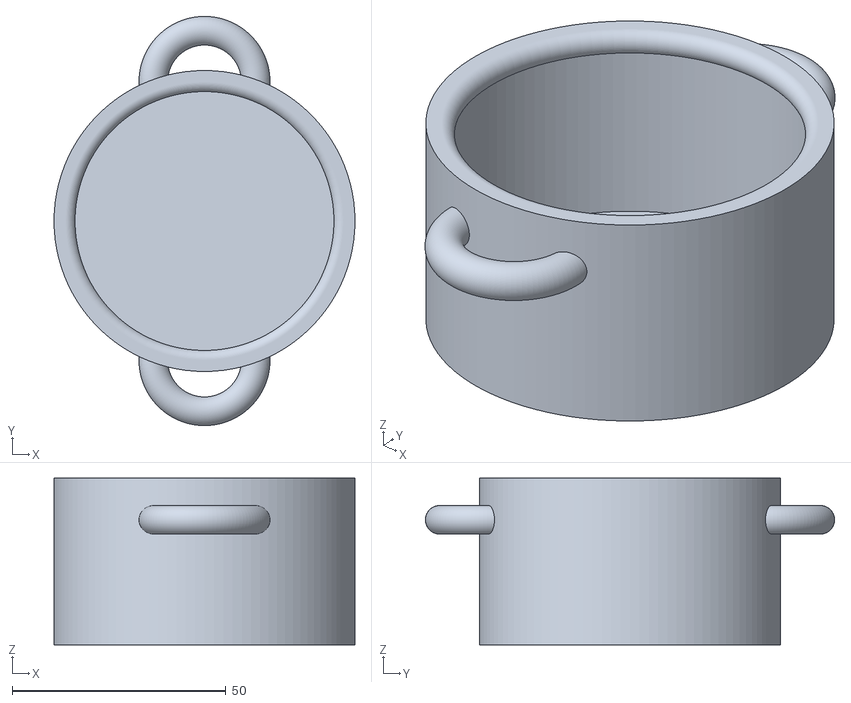
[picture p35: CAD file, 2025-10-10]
OpenFOAM/flatPot_1173K_100ml_widePot/constant/geometry/flatPotNewOne.stl
70.5 x 95.8 x 39.1

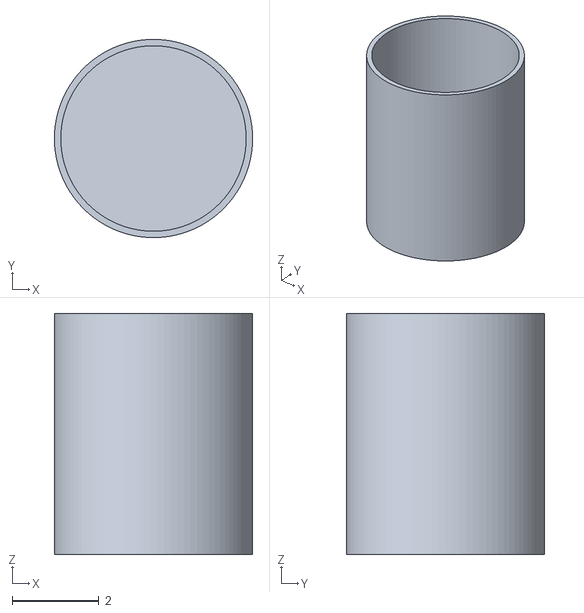
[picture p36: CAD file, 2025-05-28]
OpenFOAM/flatPot_hot/constant/geometry/flatPot1.stl
4.58 x 4.57 x 5.56

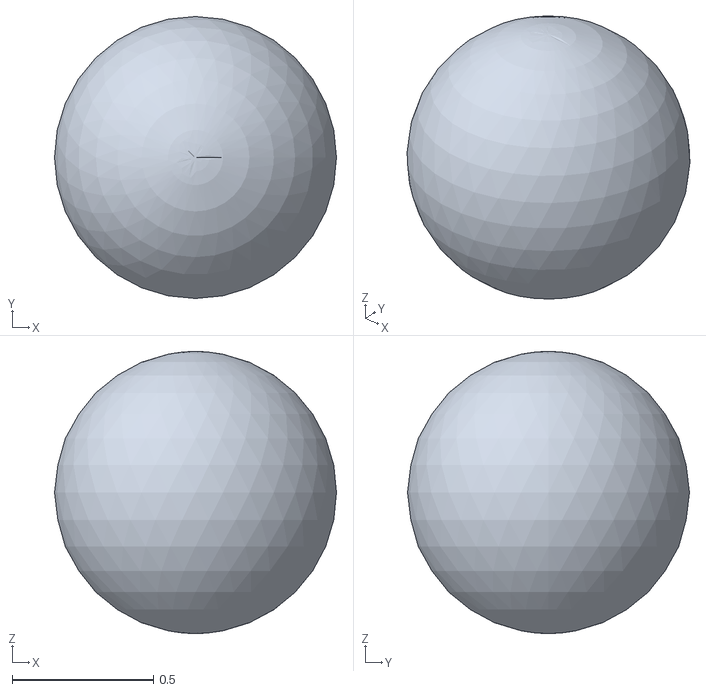
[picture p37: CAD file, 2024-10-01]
OpenFOAM/Flow-past-a-sphere-OpenFOAM/constant/triSurface/sphere.stl
1.00 x 1.00 x 1.00

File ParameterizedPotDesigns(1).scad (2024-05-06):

// Copyright Cledden Obeng-Poku Kwanin and Robert L. Read, 2024
// Released under CERN Strong-reciprocal Open Hardware License

// This is an attempt to make a new parametrized experimental apparatus
// for teting our ferrofluid check valve. It will be similar to the system
// that Veronica design in SolidWorks, but will use the improved, 360 degree design


pot_height = 5;
wall_thickness =0.5;
outer_rad =5;
inner_rad = outer_rad-wall_thickness;
base_scale_factor = 2;
height_scale_factor = 0.5;
extra_height = 3;

lid_thickness = 0.2;
lid_handle_height = 1;

finWidth = 0.2;
finLength = outer_rad/2;
finHeight = 5;

legWidth = 0.5;
legLength = outer_rad/2;
legHeight = 5;
legBallRadius = 0.4;


// ptype = "flatbottom";
// ptype = "flatbottom_with_fins";
// ptype = "roundbottom";
ptype = "roundbottom_with_fins";

// set resolution here
$fn=40;

module radialFin(angle) {
    rotate([0,0,angle])
    translate([0,outer_rad-finLength/2,-finHeight/2])
    cube([finWidth,finLength,finHeight],center=true);
}


module legFin(angle) {
    rotate([0,0,angle])
    translate([0,outer_rad-legLength/2,-outer_rad/2])
    union() {
        cube([legWidth,legLength,legHeight],center=true);
        translate([0,legLength/2,-legHeight/2])
        sphere(legBallRadius);
    }
}


module radialFins(num) {
    delta = 360 / num;
    for ( i = [0:1:num-1]) {
       radialFin(delta*i);
    }
}
module legFins(num) {
    delta = 360 / num;
    for ( i = [0:1:num-1]) {
       legFin(delta*i);
    }
}
module roundBottomOutside() {
     union () {
        color ("red")
        sphere (outer_rad);
        color("blue")
        cylinder (h=pot_height,r1=outer_rad,r2=outer_rad);
    }
}
module roundBottomPot() {
   difference() {    
        roundBottomOutside();
        union () {
            sphere (r = inner_rad);
            cylinder (h=(pot_height*2),r1 =inner_rad, r2= inner_rad);
        }
    }
}

module roundBottomPotWithFins() {
    roundBottomPot();
    difference() {
        union() {
            legFins(3);
            radialFins(12);
        }
        roundBottomOutside();
    }
}


module flatBottomPot () {
    echo("flatBottomPot Called!");
    difference () {
        cylinder (h=    pot_height, r=outer_rad, center = true);
        translate ([0,0,(wall_thickness+(extra_height/2))])
        cylinder (h=pot_height+extra_height, r1=(outer_rad-wall_thickness), r2 =(outer_rad-wall_thickness), center=true);
    }
}

module flatBottomPotOutside () {
    difference () {
        cylinder (h=    pot_height, r=outer_rad, center = true);
    }
}
module flatBottomPotWithFins() {
    flatBottomPot();
    difference() {
        radialFins(16);
        flatBottomPotOutside();
    }
}

module flatLid () {
    translate ([0,0,pot_height+1])
    rotate ([180,0,0])
    union () {
        cylinder (h= lid_thickness, r=outer_rad, center = true);
        rotate ([180,0,0])
        translate ([0,0,lid_thickness/2])
        cylinder (h= lid_handle_height, r1=lid_thickness,r2=lid_thickness*5);
    translate ([0,0,lid_thickness]);
        difference () {
         cylinder (h=lid_thickness*2, r1=(inner_rad), r2 =(inner_rad));    
        cylinder (h=(lid_thickness+extra_height), r1=(inner_rad-lid_thickness), r2 =(inner_rad-lid_thickness));
                }
            } 
}

module renderPotType(ptype) {
    if (ptype == "flatbottom") {
        flatBottomPot();
    } else  if (ptype == "flatbottom_with_fins") {
        flatBottomPotWithFins();
    } else if (ptype == "roundbottom") {
        roundBottomPot();
    } if (ptype == "roundbottom_with_fins") {
    flatLid ();  roundBottomPotWithFins();
    } 
}

difference () {
    renderPotType(ptype);
    translate([200,0,0])
    cube(100,center=true);
}

//difference () {

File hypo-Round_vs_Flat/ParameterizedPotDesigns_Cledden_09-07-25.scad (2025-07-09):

// Copyright Aditya Choksi, Cledden Obeng-Poku Kwanin, and Robert L. Read, 2024
// Released under CERN Strong-reciprocal Open Hardware License

// This is an attempt to make a new parametrized experimental apparatus
// for teting our ferrofluid check valve. It will be similar to the system
// that Veronica design in SolidWorks, but will use the improved, 360 degree design


excess_lip_scale_factor = 1.3;

PI = 3.141592;

// TODO: we need a good module for the D-handles.
// Right now that code is spread across a lot of places.

// TODO: An Aspect Ratio for flat pots can be less than 1,
// but not for round-bottomed pots. We should reorganize 
// the code to take that into account.

// Currently if the Aspect Ratio is <= 1.0, the bot is not defined.
// A = 1.3; // aspect ratio (pure number) for rounded pots
A = 1.3; // aspect ratio for flat pots
V_ml = 100; 
// 1 ml = 1000 mm^3
V_water = V_ml*1000;
V_pot = ((V_ml*1000)*excess_lip_scale_factor); // cubic millimeters (thousandths of a mililter)


// This math done by Cledden...
// H = heigh will be a computed value
// S = height of the side 

// R = radius of the pot (mm)
// D = diaeter of the pot
// A = H/D
// H = R + S
// D = 2R
// VP = Vcy + Vhs (Total volume volume of hemisphere + volume of cylinder
// VP = PI * R^2 * (H - R) + 2/3 * PI * R^3
// ... collecting PI * R^2
// VP = PI * R^2 [(H-R) + 2/3 * R]
// ... substitute H = A * R
// VP = PI * R^2 [(A*R - R) + 2/3 *R]
// VP = PI * R^3 [(A - 1) + 2/3]
// VP = PI * R^3 [A - 1/3]
// R = pow(VP / (PI *(A - 1/3)),1/3)


function radius(A,V) = pow(V / (PI *(A - 1/3)),1/3);

// This is the aspect ratio times the radius...
// This is now unclear to me
function height(A,V) = A * radius(A,V);

function side(A,V) = height(A,V) - radius(A,V);



// In this case, A = H / (2R)
// V = H * PI * R^2 
// V = (A * 2R ) PI * R^2 =  2 * PI * AR^3
// R = pow(V / ( 2 * PI * A), 1/3);

function cyl_radius(A,V) = pow(V / ( 2 * PI * A), 1/3);
function cyl_height(A,V) = A*(2*cyl_radius(A,V));

echo(radius(A,V_pot));
echo(height(A,V_pot));

echo("cyl radius");
echo(cyl_radius(A,V_pot));
echo("cyl height");
echo(cyl_height(A,V_pot));

radius_mm = radius(A,V_pot);

wall_thickness = radius_mm/40;

base_scale_factor = 2;
height_scale_factor = 0.5;
extra_height = radius_mm/40;

lid_thickness = radius_mm/12;
lid_knob_height = radius_mm/5;
knob_scale_factor = 2;
lid_wall_size = sqrt(lid_thickness);
lid_scale_factor =  0.5;

lid_hook_height = radius_mm/6;
lid_hook_gap_tolerance = radius_mm/14;
lid_hook_thickness = radius_mm/30;
lid_hook_connector_height = radius_mm/60;
lid_extender_angle_scale = 0.9;

lid_handle_radius = radius_mm*0.6;
lid_handle_thickness = radius_mm/6;
lid_handle_wall_thickness = radius_mm/40;
lid_handle_scale_factor = 1.2;


conical_lid_scale_factor = 0.7;
conical_lid_height = radius_mm/0.8;

conical_end_height = radius_mm/4;
conical_end_scale_factor = 1.33;

pot_handle_radius = radius_mm/2.4;
pot_handle_thickness = radius_mm/6;
// pot_handle_wall_thickness = radius_mm/40;
pot_handle_wall_thickness = radius_mm/80;
handle_position = -(radius_mm/6);

// lid_distance_from_pot = radius_mm/1.2;
lid_distance_from_pot = radius_mm/2.8;


finWidth = wall_thickness;
// finLength = outer_rad/2;
// finHeight = 5;

legWidth = wall_thickness;
// legLength = outer_rad/2;
// legHeight = 5;
legBallRadius = radius_mm/10;


// ptype = "flatbottom";
//ptype = "flatbottom_with_fins";
//ptype = "roundbottom";
//ptype = "roundbottom_with_fins";
 ptype = "roundbottom_with_handles";
//ptype = "roundbottom_with_fins_and_handles";
// ptype = "none";
rim_bead_radius = lid_thickness/2;
if (ptype == "flatbottom") {
    rim_bead_radius = lid_thickness;
} else {
    rim_bead_radius = min(3,side(A,V_pot));
}
echo("rim_bead_radius");
echo(rim_bead_radius);

 ltype = "none";
// ltype = "flat_lid"; // -- incorrect!
// ltype = "solidconical"; // -- incorrect!
// ltype = "hollowconical"; 
// ltype = "hollowconicalwithconcavelid";





 //ctype = "roundBottomPot_content"; //added by Cleddden for Pot content
// ctype = "flatBottomPot_content";//added by Cleddden for Pot content
ctype = "none"; //added by Cleddden for Pot content

// set resolution here
// This is good for fast rendering
// $fn=30;
$fn = 100;

module roundedFin(Fw,Fl,Fh){
    color ("red")
    //cube([Fw,Fl,Fh],center=true);
    resize(newsize=[Fw,Fl,Fh])
        sphere(Fh);
}

module cubeFin(Fw,Fl,Fh){
    color ("purple")
    cube([Fw,Fl,Fh],center=true);
}


module radialFin(r,angle) {
    ro = r + wall_thickness;
    finLength = ro/2;
    finHeight = ro;
        rotate([0,0,angle])
        translate([0,ro-finLength/2,-finHeight/2])
        roundedFin(finWidth*3,finLength*1.5,finHeight);
}


module legFin(r,angle) {
    ro = r + wall_thickness;
    legLength = ro/2;
    legHeight = ro;
    rotate([0,0,angle])
    translate([0,ro-legLength/2,-ro/2])
    union() {
        //cubeFin(legWidth,legLength,legHeight);
        translate([0,legLength/2 - legBallRadius,-legHeight/2])
        sphere(legBallRadius);
    }
}


module radialFins(r,num) {
    delta = 360 / num;
    for ( i = [0:1:num-1]) {
       radialFin(r,delta*i);
    }
}
module legFins(r,num) {
    delta = 360 / num;
    for ( i = [0:1:num-1]) {
       legFin(r,delta*i);
    }
}
module triangularFins(r,num) {
    delta = 360 / num;
    for ( i = [0:1:num-1]) {
       triangularFinMK(r,delta*i);
    }
}

module roundBottomOutside(A,V) {
    radius_mm = radius(A,V);
    side_h = side(A,V);
     union () {
        color ("green")
        difference() {
            sphere (radius_mm+wall_thickness);
            translate([0,0,radius_mm*2])
            cube(radius_mm*4,center=true);
        }
        
        // now we add the rim and cut away a cone to make a 
        // Conical fit for the rim.
        color("blue")
        difference() {
            cylinder (h=side_h,r1=radius_mm+wall_thickness,r2=radius_mm+wall_thickness);
        }
    }
}



module roundBottomPot(A,V) {
   radius_mm = radius(A,V);
   side_h = side(A,V);
    union() {
       difference() {    
            roundBottomOutside(A,V);
            union () {
                sphere (r = radius_mm);
                translate([0,0,1])
                cylinder (h=side_h+1,r1 =radius_mm, 
                r2= radius_mm);
            }
        }
        translate([0,0,side_h-rim_bead_radius])
        potInterface(radius_mm,radius_mm+wall_thickness,rim_bead_radius);
    }
}

module roundBottomPotWithFins(A,V) {
    radius_mm = radius(A,V);
    roundBottomPot(A,V);

    difference() {
        union() {
            legFins(radius_mm,3);
            triangularFins(radius_mm,18);
            //radialFins(radius_mm,12);
        }
        roundBottomOutside(A,V);
    }
}

module roundBottomPotWithHandles(A,V){
    radius_mm = radius(A,V);
    side_h = side(A,V);
    roundBottomPot(A,V);
    
    union(){
        roundBottomPot(A,V);
        
    handle(A,V,ptype,radius_mm);
    handle(A,V,ptype,-radius_mm);
    }    
}
module roundBottomPotWithHandlesAndFins(A,V){
    radius_mm = radius(A,V);
     side_h = side(A,V);
    roundBottomPotWithFins(A,V);
    
    union(){
        roundBottomPotWithFins(A,V);
        handle(A,V,ptype,radius_mm);
        handle(A,V,ptype,-radius_mm);
    }
}

module flatBottomPot (A,V) {
    radius_mm = cyl_radius(A,V);
    outer_rad = cyl_radius(A,V) + wall_thickness;
    echo("outer_rad");
    echo(outer_rad);
    pot_height = cyl_height(A,V);
    #union(){
        translate([0,0,pot_height/2 - rim_bead_radius])
        potInterface(radius_mm,radius_mm+wall_thickness,rim_bead_radius);
        difference () {
            cylinder (h=    pot_height, r=outer_rad, center = true);
            translate ([0,0,(wall_thickness+(extra_height/2))])
            cylinder (h=pot_height+extra_height, r1=(outer_rad-wall_thickness), r2 =(outer_rad-wall_thickness), center=true);
        
    }
    handle(A,V,ptype,radius_mm);
    handle(A,V,ptype,-radius_mm);
}    
}

module flatBottomPotOutside () {
    difference () {
        cylinder (h=    pot_height, r=outer_rad, center = true);
    }
}
module flatBottomPotWithFins() {
    flatBottomPot();
    difference() {
        radialFins(16);
        flatBottomPotOutside();
    }
}

//this module was added by Cledden
module flatBottomPot_content (A,V_pot,V_water) {
    outer_rad = cyl_radius(A,V_pot) + wall_thickness;
    echo("outer_rad");
    echo(outer_rad);
    // I think this is wrong...we want to use 
    // the cyl_radius to compute the water...
    pot_height = cyl_height(A,V_pot);
    water_height = pot_height * V_water/V_pot;
    
        translate ([0,0,wall_thickness/2])
    translate([0,0,-(pot_height - water_height)/2])
    color ("blue")
        cylinder (h=(water_height-(wall_thickness)),r1 =(outer_rad-wall_thickness), r2 =(outer_rad-wall_thickness), center=true);
}
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

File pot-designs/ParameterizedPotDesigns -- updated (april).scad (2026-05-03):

//VERSION = 1.01;
excess_lip_scale_factor = 1.3; //increase the size of h
PI = 3.141592;
USE_VERTICAL_POT_KNIFE = false;
$fn = 64;
ptype = "wavy";


RIM_RADIUS = 70; 
BASE_HEIGHT = 70; 
HEIGHT_STRETCH = 0.7; 
LID_FACTOR = 4; 
POT_VERTICAL_OFFSET = 48; 
Amp = 20; 
N = 4;  

WALL = RIM_RADIUS / 25;  
OUTER_R = RIM_RADIUS + WALL;
H = BASE_HEIGHT; 
rim_bead_radius = RIM_RADIUS / 25;
lid_thickness = WALL;

// Wave Math Tweaks
v_exp = 0.2; 
thickness = 1; 
scale_coeff = 1.1; 

// Handle Settings
lid_handle_radius = RIM_RADIUS * 0.6;          
lid_handle_thickness = RIM_RADIUS / 6;       
pot_handle_radius = RIM_RADIUS / 2.0; 
pot_handle_thickness = RIM_RADIUS / 6;
handle_position_z = -10; 

real_z_at_rim = (BASE_HEIGHT == RIM_RADIUS) ? BASE_HEIGHT : sqrt(max(0, pow(H, 2) - pow(RIM_RADIUS, 2)));
pot_total_height = real_z_at_rim * HEIGHT_STRETCH;
conical_lid_scale_factor = 0.7;
lid_height = (H * 0.45) * HEIGHT_STRETCH * LID_FACTOR; 

// Grid setup for polyhedrons
grid_size = 100; 
dx = (2 * OUTER_R)/grid_size;
dy = (2 * OUTER_R)/grid_size;

// change these together! 
POT_BOTTOM_SHAPE_FLAT = false;
//ptype = "flatbottom";
//ptype = "flatbottom_with_fins";
// ptype = "roundbottom";
//ptype = "roundbottom_with_fins";
// ptype = "roundbottom_with_handles";
// ptype = "studs";
// ptype = "roundbottom_with_fins_and_handles";
// ptype = "none";

//ctype = "roundBottomPot_content";
//ctype = "flatBottomPot_content";
ctype = "none"; 
 
// ltype = "none";
// ltype = "flat_lid"; // -- incorrect!
// ltype = "solidconical"; // -- incorrect!
// ltype = "hollowconical"; 
// ltype = "hollowconicalwithconcavelid";
 ltype="conicalLidIvan";

// TODO: we need a good module for the D-handles.
// Right now that code is spread across a lot of places.

// This is the type for the adapter for testing
 ttype = "none";
// ttype = "threestone";
// ttype = "printableThreeStone";



ftype = "thin";
// ftype = "thick";
fin_sharpness_thin = 1.0;
fin_sharpness_thick = 8.0;

fin_sharpness = 1.0;

HALF_FINS = "true"; // This controls intermediary fins between the main heat transfer fins
// HALF_FINS = "false";

adapter_h_mm = 30;
adapter_r_mm = 35/2;
adapter_w_mm = 2;

// TODO: An Aspect Ratio for flat pots can be less than 1,
// but not for round-bottomed pots. We should reorganize 
// the code to take that into account.


// Currently if the Aspect Ratio is <= 1.0, the bot is not defined.
//if (POT_BOTTOM_SHAPE_FLAT) {
//    A = 0.6; // aspect ratio for flat pots
//} else {
//    A = 1.3; // aspect ratio (pure number) for rounded pots
//}
A = POT_BOTTOM_SHAPE_FLAT ? 0.6 : 1.3;

echo("A");
echo(A);

V_ml = 100; 
// 1 ml = 1000 mm^3
V_water = V_ml*1000;
V_pot = ((V_ml*1000)*excess_lip_scale_factor); // cubic millimeters (thousandths of a mililter)


// This math done by Cledden...
// H = heigh will be a computed value
// S = height of the side 

// R = radius of the pot (mm)
// D = diaeter of the pot
// A = H/D
// H = R + S
// D = 2R
// VP = Vcy + Vhs (Total volume volume of hemisphere + volume of cylinder
// VP = PI * R^2 * (H - R) + 2/3 * PI * R^3
// ... collecting PI * R^2
// VP = PI * R^2 [(H-R) + 2/3 * R]
// ... substitute H = A * R
// VP = PI * R^2 [(A*R - R) + 2/3 *R]
// VP = PI * R^3 [(A - 1) + 2/3]
// VP = PI * R^3 [A - 1/3]
// R = pow(VP / (PI *(A - 1/3)),1/3)


function radius(A,V) = pow(V / (PI *(A - 1/3)),1/3);

// This is the aspect ratio times the radius...
// This is now unclear to me
function height(A,V) = A * radius(A,V);

function side(A,V) = height(A,V) - radius(A,V);



// In this case, A = H / (2R)
// V = H * PI * R^2 
// V = (A * 2R ) PI * R^2 =  2 * PI * AR^3
// R = pow(V / ( 2 * PI * A), 1/3);

function cyl_radius(A,V) = pow(V / ( 2 * PI * A), 1/3);
function cyl_height(A,V) = A*(2*cyl_radius(A,V));

echo(radius(A,V_pot));
echo(height(A,V_pot));

echo("cyl radius");
echo(cyl_radius(A,V_pot));
echo("cyl height");
echo(cyl_height(A,V_pot));

radius_mm = radius(A,V_pot);

tester_mm = radius_mm*2;

// This is the radius to hold the heat gun.
adapter_mm = 60;




// wall_thickness = radius_mm/20;
wall_thickness = radius_mm/30;

base_scale_factor = 2;
height_scale_factor = 0.5;
extra_height = radius_mm/40;


lid_knob_height = radius_mm/5;
knob_scale_factor = 2;
lid_wall_size = sqrt(lid_thickness);
lid_scale_factor =  0.5;

lid_hook_height = radius_mm/6;
lid_hook_gap_tolerance = radius_mm/14;
lid_hook_thickness = radius_mm/30;
lid_hook_connector_height = radius_mm/60;
lid_extender_angle_scale = 0.9;


lid_handle_wall_thickness = radius_mm/40;
lid_handle_scale_factor = 1.2;



conical_lid_height =POT_BOTTOM_SHAPE_FLAT ? radius_mm/1.3 : radius_mm/0.8;

conical_end_height = radius_mm/4;
conical_end_scale_factor = 1.33;




pot_handle_wall_thickness = radius_mm/40;
handle_position = -(radius_mm/6);

// lid_distance_from_pot = radius_mm/1.2;
lid_distance_from_pot = radius_mm/2.8;


module roundedFin(Fw,Fl,Fh){
    color ("red")
    //cube([Fw,Fl,Fh],center=true);
    resize(newsize=[Fw,Fl,Fh])
        sphere(Fh);
}

module cubeFin(Fw,Fl,Fh){
    color ("purple")
    cube([Fw,Fl,Fh],center=true);
}


module radialFin(r,angle) {
    ro = r + wall_thickness;
    finLength = ro/2;
    finHeight = ro;
        rotate([0,0,angle])
        translate([0,ro-finLength/2,-finHeight/2])
        roundedFin(finWidth*3,finLength*1.5,finHeight);
}


module legFin(r,angle) {
    ro = r + wall_thickness;
    legLength = ro/2;
    legHeight = ro;
    rotate([0,0,angle])
    translate([0,ro-legLength/2,-ro/2])
    union() {
        //cubeFin(legWidth,legLength,legHeight);
        translate([0,legLength/2 - legBallRadius,-legHeight/2])
        sphere(legBallRadius);
    }
}


module radialFins(r,num) {
    delta = 360 / num;
    for ( i = [0:1:num-1]) {
       radialFin(r,delta*i);
    }
}
module legFins(r,num) {
    delta = 360 / num;
    for ( i = [0:1:num-1]) {
       legFin(r,delta*i);
    }
}
module triangularFins(r,num) {
    delta = 360 / num;
    for ( i = [0:1:num-1]) {
       triangularFinMK(r,delta*i,false);
    }
    if (HALF_FINS) {
        for ( i = [0:1:num-1]) {
           triangularFinMK(r,delta*i+delta/2,true);
        }
    }
}

module roundBottomOutside(A,V) {
    radius_mm = radius(A,V);
    side_h = side(A,V);
     union () {
        color ("green")
        difference() {
            sphere (radius_mm+wall_thickness);
            translate([0,0,radius_mm*2])
            cube(radius_mm*4,center=true);
        }
        
        // now we add the rim and cut away a cone to make a 
        // Conical fit for the rim.
        color("blue")
        difference() {
            cylinder (h=side_h,r1=radius_mm+wall_thickness,r2=radius_mm+wall_thickness);
        }
    }
}



module roundBottomPot(A,V) {
   radius_mm = radius(A,V);
   side_h = side(A,V);
    union() {
       difference() {    
            roundBottomOutside(A,V);
            union () {
                sphere (r = radius_mm);
                translate([0,0,1])
                cylinder (h=side_h+1,r1 =radius_mm, 
                r2= radius_mm);
            }
        }
        translate([0,0,side_h-rim_bead_radius])
        potInterface(radius_mm,radius_mm+wall_thickness,rim_bead_radius);
    }
}

module roundBottomPotWithFins(A,V) {
    radius_mm = radius(A,V);
    roundBottomPot(A,V);

    difference() {
        union() {
            legFins(radius_mm,3);
            triangularFins(radius_mm,18);
            //radialFins(radius_mm,12);
        }
        roundBottomOutside(A,V);
    }
}

module roundBottomPotWithHandles(A,V){
    radius_mm = radius(A,V);
    side_h = side(A,V);
    roundBottomPot(A,V);
    
    union(){
        roundBottomPot(A,V);
        
    handle(A,V,ptype,radius_mm);
    handle(A,V,ptype,-radius_mm);
    }    
}
module roundBottomPotWithHandlesAndFins(A,V){
    radius_mm = radius(A,V);
     side_h = side(A,V);
    roundBottomPotWithFins(A,V);
    
    union(){
        roundBottomPotWithFins(A,V);
        handle(A,V,ptype,radius_mm);
        handle(A,V,ptype,-radius_mm);
    }
}

module flatBottomPot (A,V) {
    radius_mm = cyl_radius(A,V);
    outer_rad = cyl_radius(A,V) + wall_thickness;
    echo("outer_rad");
    echo(outer_rad);
    pot_height = cyl_height(A,V);
    union(){
        translate([0,0,pot_height/2 - rim_bead_radius])
        potInterface(radius_mm,radius_mm+wall_thickness,rim_bead_radius);
        difference () {
            cylinder (h=    pot_height, r=outer_rad, center = true);
            translate ([0,0,(wall_thickness+(extra_height/2))])
            cylinder (h=pot_height+extra_height, r1=(outer_rad-wall_thickness), r2 =(outer_rad-wall_thickness), center=true);
        
    }
    translate([0,0,pot_height/4]) {
        union() {
            handle(A,V,ptype,radius_mm);
            handle(A,V,ptype,-radius_mm);
        }
    }
}    
}
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

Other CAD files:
Prototypes and Testing--Rice Team/Models _ Simulations/Generation 3 Models - Half Radial Fin Iterations + Fin Guard Models/Cornerguard Assembly.SLDPRT
Prototypes and Testing--Rice Team/Models _ Simulations/Generation 3 Models - Half Radial Fin Iterations + Fin Guard Models/Wireframe Assembly.SLDPRT
OpenFOAM/CleddenTest/constant/extendedFeatureEdgeMesh/air_edgeMesh.obj
OpenFOAM/ecoPot2/constant/extendedFeatureEdgeMesh/pot_internalEdges.obj
OpenFOAM/erlenmeyer_pot_16605mm_wall_thickness/constant/extendedFeatureEdgeMesh/erlenmeyerPot_externalEdges.obj
OpenFOAM/Flow-past-a-sphere-OpenFOAM/constant/extendedFeatureEdgeMesh/sphere_convexFeaturePts.obj
OpenFOAM/rectangularPot_case/constant/extendedFeatureEdgeMesh/rectangularPot_edgeMesh.obj
pot-designs/ParameterizedPotDesigns.scad
OpenFOAM/CleddenTest/constant/extendedFeatureEdgeMesh/flatPotContentNew_edgeDirections.obj
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

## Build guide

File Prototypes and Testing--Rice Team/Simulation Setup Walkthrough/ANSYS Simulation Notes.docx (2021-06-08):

- 12/6
  - Tried basic tutorial on water fluid flow
  - Put in helical venting pot
    - Displayed direction field, hit x for cross sectional view
    - Smoke is moving really slowly inside the vent (before edits that Dr. Read suggested, so maybe it’s just that the vents aren’t big enough for much air to come through)

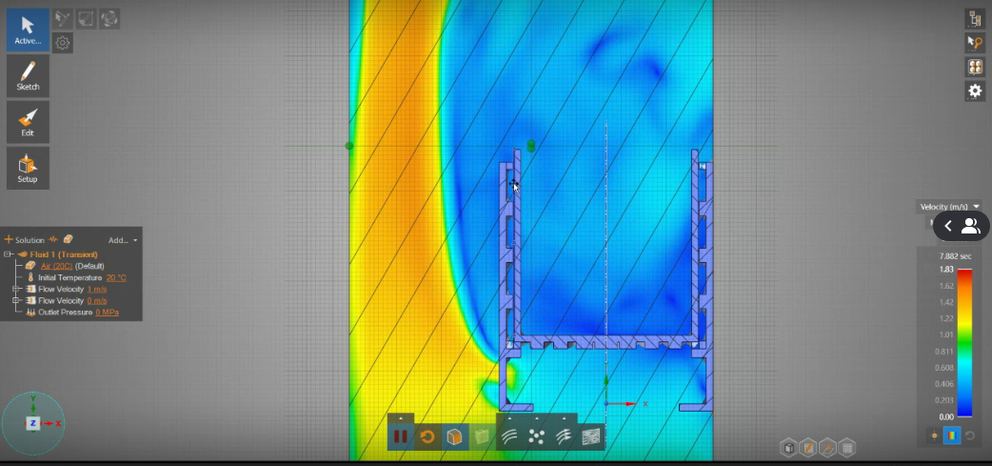
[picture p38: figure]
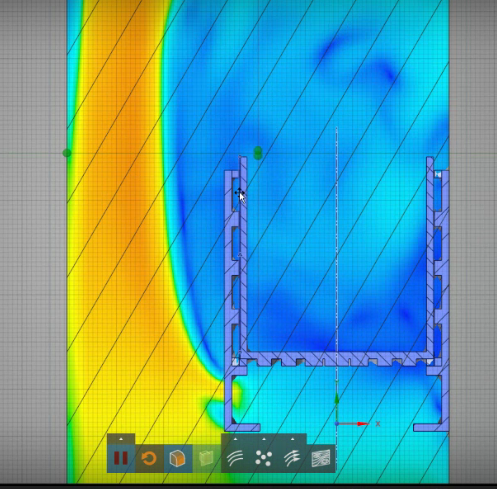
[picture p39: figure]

- Made outside layer really thick and vents really large

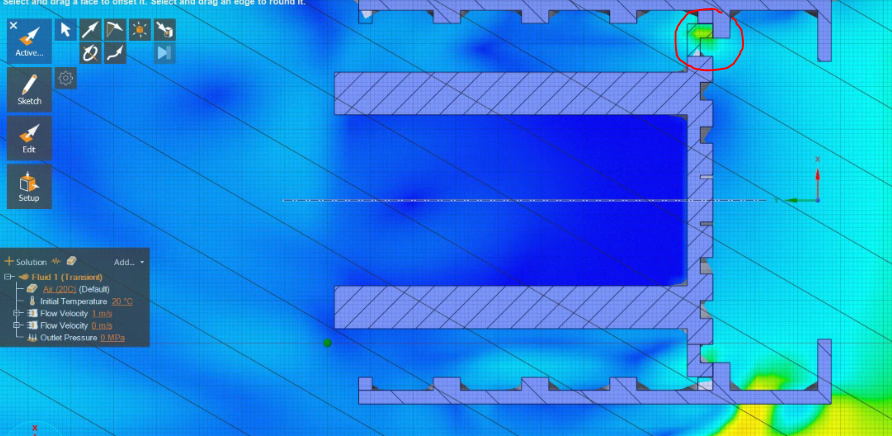
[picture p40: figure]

  - Looks like the vents are being blocked a bit? Which corroborates what Sam was talking about when he printed the helical vane pot
- Moved inner layer up a lot just to see what it would be like if there’s no blockage at the bottom of the pot

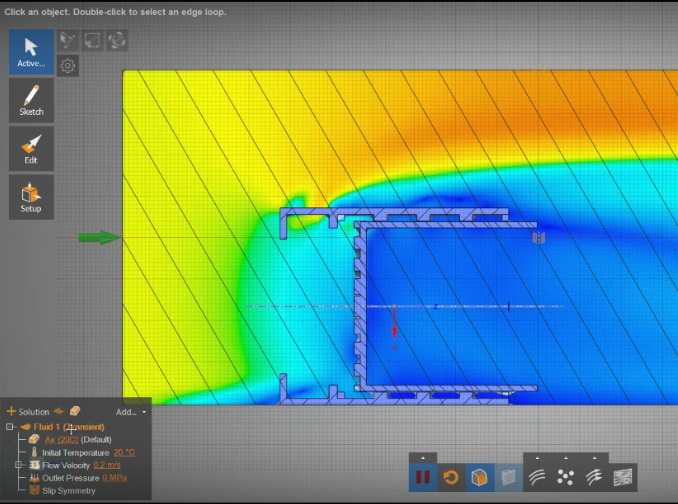
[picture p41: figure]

  - Air moves really slowly inside vents for now, which might be a good thing if there’s longer time exposure between the smoke in the vents and the walls of the pot
- Adding an emitter to see the flow of air particles

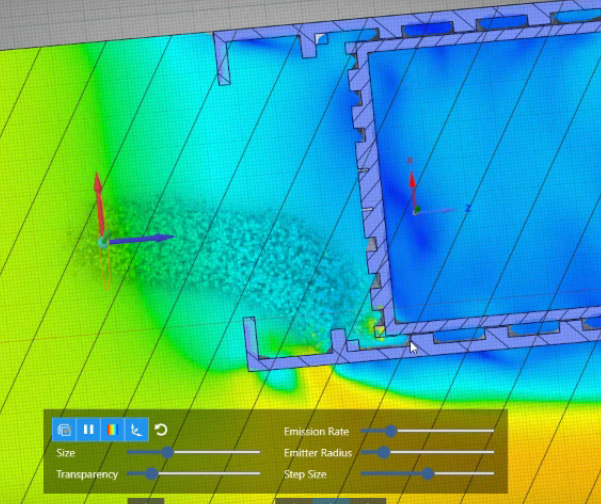
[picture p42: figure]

  - Seems like the particles disappear as soon as they contact the surface, so can’t really see the movement of the particles inside the vents

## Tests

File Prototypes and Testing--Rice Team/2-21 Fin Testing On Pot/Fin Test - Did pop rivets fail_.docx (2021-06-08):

- 2.8L of water in the pot
- Heated to third notch on dial
- Use scrap metal to balance pot on the stove
- Water dripping from second fin (caulking)
  - Could be condensation or failed joint
  - WAS CONDENSATION
- Fins directing heat
  - Condensation on the side of the pot where the fins are directing the heat
- Dripping on the side where there are no fins
  - Condensation
- Boiling faster on the side that is directly over the fire
- Rivets look like the edges are peeling
- Letting it boil for 30min or come to rolling boil whichever is first
- Pot discoloration
  - Metal in the epoxy so maybe it oxidized in
- Epoxied not riveted
  - Popped off a little bit when a lot of force was applied
- Pot dropped three times (from Chris’ waist length)
  - Pot dented from the bottom
  - The epoxy held up
  - The fins bent
  - Still water proof
    - No water leaked
- None of them leaked
  - Caulking not necessary
  - Can just rivet and seal with epoxy
- Takeaways
  - Can proceed with full size prototypes using the pop rivets and no caulking
  - Limiting factors are the pots
  - Whenever pots arrive we can continue with prototype
- Ask Dr. Elliot
  - How to attach the safeguard to the bottom of the pot
- Dimension of the pot
  - For scaling fin lengths to pot
- Tack weld
  - GSI pot
- Laser weld
  - Blue pot

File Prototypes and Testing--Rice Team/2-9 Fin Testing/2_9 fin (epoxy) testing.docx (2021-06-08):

Fin Testing Over Fire

MG Chemicals → Medium Cure thermally Conductive Adhesive

- Fins on clamp 10.5cm above the flame
  - ***measured from clamp base not table
- Burner 3 notches
  - Temp reading →
    - Fins Max around 300-400F
- Fins removed from flame at 5 min
  - Clamped fin began to brown
- Both fins came off easily
  - Clamp didn't make a difference

After a few seconds on the fire, the rubber on the clamp started melting. We then used a new set up with a metal clamp (same conditions as above except)

- 9.9 cm from the base

JB Weld → ExtremeHeat temperature resistant Metallic Repair Paste

- Fins on clam
- 9.9 cm from base
- The non-clamped fin fell off without any pressure
- The clamped fin fell off with barely any pressure (much less compared to MG)

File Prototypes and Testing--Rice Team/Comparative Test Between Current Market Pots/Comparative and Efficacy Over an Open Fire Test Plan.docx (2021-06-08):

Comparative Efficacy Test Over an Open Fire Plan

Reference (https://www.youtube.com/watch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) Test

- 2-3 minutes to boil 1L water

Materials:

- ~~Thermal Camera for iPhone~~ (https://www.amazon.com/FLIR-One-Thermal-Imager-For/dp/B0728C7KND) ~~$199.99~~
- Fire starter $3.95
- Fire wood
- ~~Fire pit?~~
- ~~Regular pot~~
  - ~~Sea to summit alpha pot 1.9 L $44.95~~ (https://www.rei.com/product/128506/sea-to-summit-alpha-pot-19-liters)
    - ~~Best Use Backpacking Liquid Capacity (L) 1.9 liters Liquid Capacity (fl. oz.) 64 fluid ounces~~
    - ~~Dimensions 6.5 x 4.7 inches~~
    - ~~Cookware Material Aluminum Material(s) Hard-anodized alloy~~
    - ~~Nonstick Surface No~~
    - ~~Includes 1.9L pot; strainer lid Weight 8.1 ounces~~
  - GSI boiler pot 1.8 L $37.50 (https://www.rei.com/product/107822/gsi-outdoors-halulite-boiler-pot-18-liters)
    - Liquid Capacity (L) 1.8 liters Liquid Capacity (fl. oz.) 61
    - Dimensions 6.0 x 5.8 x 5.6 in. inches
    - Cookware Material Aluminum Material(s) Hard Anodized Aluminum
    - Nonstick Surface No Includes
    - 1.8 Liter Boiler, Lid, Mesh Stuff Sack Weight 11 oz. ounces
- ~~Heat exchanger pot~~
  - GSI pot 1.8 L $89.95 (https://www.rei.com/product/165301/gsi-outdoors-pinnacle-dualist-hs-cookset)
    - Best Use Backpacking
    - Dimensions 6.2 x 5.9 x 5.8 inches Cookware
    - Material Stainless Steel Material(s) Nonstick coated/hard anodized aluminum/PP/nylon/silicone/aluminum/stainless steel
    - Nonstick Surface Yes
    - Includes 1.8L pot strainer lid; 2 mugs (20 fl. oz.) with insulated sleeves; 2 bowls (20 fl. oz.); 2 sip-it tops; 2 folding foons; welded sink Ultralight Yes Weight 1 lb. 7.1 oz.
  - MSR wind burner duo pot 1.8 L $179.95 (https://www.rei.com/product/897576/msr-windburner-pot-18-liters)
    - Best Use Backpacking Liquid Capacity (L) 1.8 liters Liquid Capacity (fl. oz.) 61 fluid ounces
    - Dimensions 5 x 8 inches
    - Cookware Material Aluminum Material(s) Aluminum/plastic
    - Includes Pot; strainer/drinking lid; cozy; bowl; canister stand Weight 13 ounces

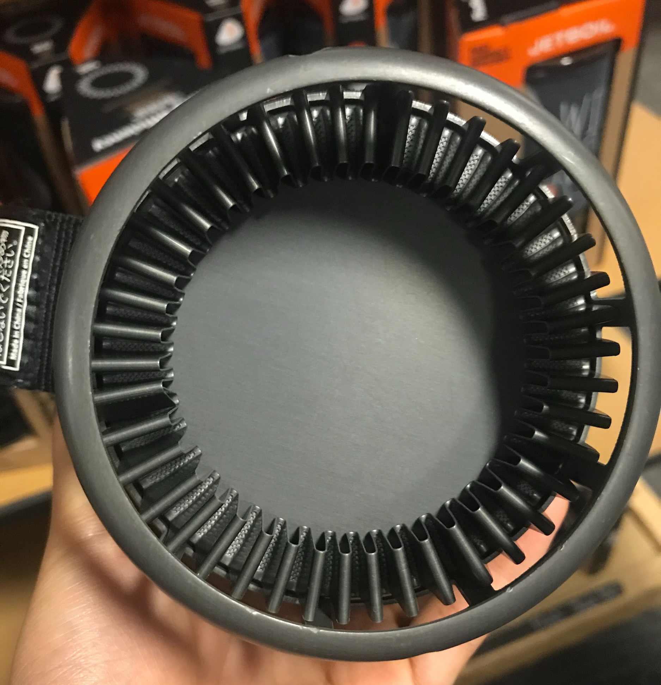
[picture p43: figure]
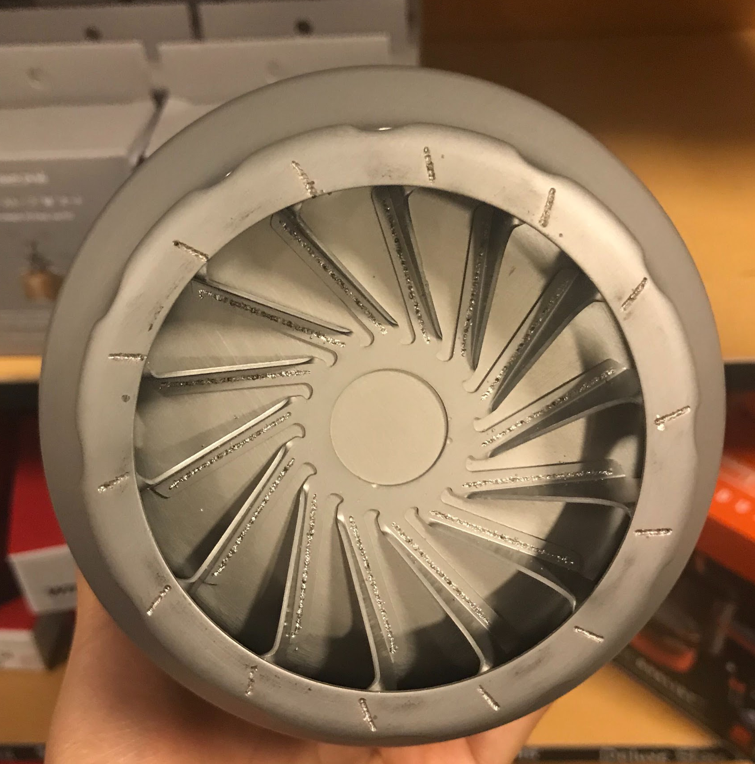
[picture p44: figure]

- OEDK
  - thermometers
  - Thermocouplers
  - IR gun
- MISC
  - Measuring cup
  - Oven mitts
  - Tongs
  - ~~Rocks - Home Depot/Lowe’s~~
    - Landscaping store
  - 3 gallons of distilled water

Location (https://houston.cbslocal.com/top-lists/top-spots-for-a-bonfire-in-houston/): Call to confirm that we can start a fire

- McMurty - ask if we can start a fire? (Brian Gibson)
- Hanszen -
- Someone’s backyard
  - Sana’s?
- Sheldon Lake (281) 456-2800
- SFA (979) 885-3613
- Galveston State park 9798853613
- Lake Livingston State Park (936) 365-2201
- (take a picture of gas/miles before and after + keep receipts)

Procedure

1. Set up the stones or something else to support the pot
2. Set up the fire
  a. Take three separate measures of the fire’s temp with the IR gun
3. Measure the temperature of the distilled water at room temperature
  a. Take three separate measures
4. Fill the pot with 1.5L of room temperature water and put on the fire
  a. If the thermometer fits (for both the lid and without lid test), leave it in the water
  b. Once the water has boiled record the temperature from the thermometer
5. Point the IR camera at the pot and record until the water has boiled
6. Meanwhile point the IR gun at the bottom of the pot (if possible…)
  a. Take three separate measures every 30 seconds
7. Once the water has boiled take the pot off of the fire
  a. Place down where?
  b. Continue recording the pot with the IR camera for 5? 10? Minutes afterwards
    i. To see how and the time it takes for the heat to dissipate
8. Repeat will all the pots

Questions

- Will we be measuring the time it takes to boil with a lid and without a lid?
  - With a lid test
    - how will I check to see if the water is boiling without lifting the lid too many times?
    - How will I check temperature - depending on length of the thermometer, it may prevent the lid from closing all the way

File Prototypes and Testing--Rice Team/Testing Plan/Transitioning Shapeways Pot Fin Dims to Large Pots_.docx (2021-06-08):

In order to keep consistency between the large aluminum pots and the smaller shapeways pots, we needed to translate the fin dimensions of length and depth from the smaller models to the new larger ones (fin width will not be scaled due to material limitations). These lengths were calculated by scaling the 2 inch shapeways pot designs to 15 inches, and taking those calculations into account.

Fin height will always be 17mm / 0.67”

The flaps should be at least 19mm / 0.75”

So when you cut out the fins make them 36mm / 1.42” wide/high/across

Horizontal Fin Pot (Parallel Fins)

7 parallel fins

The fins are varying in length, with one fin along the center of the pot and the rest spaced at 1.08 inch offsets in parallel to the center fin. So there should be 5 fins on either side of the center fin

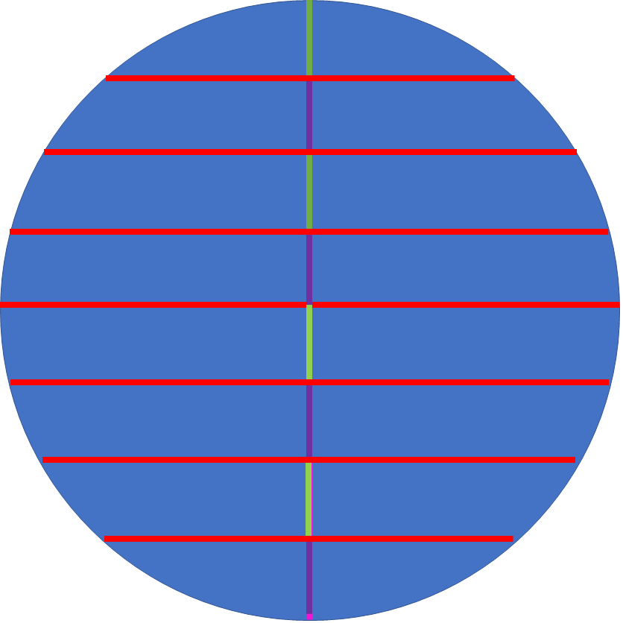
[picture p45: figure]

From the center the fins follow the following length:

Center fin: 8.66 inches 220 mm

1st Offset: 8.37 inches 212.6 mm

2nd Offset: 7.45 inches 189 mm

3rd Offset: 5.71 inches 145 mm

Full Radial Fin Pot

10 radial fins - 5.172 inches 131 mm in length

The fins are spaced equidistant along the pot, and start at the edge of the pot and point inward. They should reach the center of the pot, or at least close to it.

Half Radial Fin Pot

20 radial fins - 2.586 inches 66 mm in length

The fins are spaced equidistant along the pot, and start at the edge of the pot and point inward. They should only reach around halfway to the center of the pot

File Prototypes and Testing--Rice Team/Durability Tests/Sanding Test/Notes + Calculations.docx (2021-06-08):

4 by 36 inch belt sanding, 3600 rpm

129,600 inch per minute

R2601 orbital sander - lowest setting is 7000 rpm

Sandpaper - p180 grit

2 minutes on lowest setting, bottom of inside and outside

See before and after pictures in the slide

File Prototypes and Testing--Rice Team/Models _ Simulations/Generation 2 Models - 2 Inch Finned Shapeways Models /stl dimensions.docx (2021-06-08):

All

Base: diameter 2in

Half fin Radial

- Length 12.72mm
- Width 3.64
- Tall 4.31
- 20 fins
- Area 23.45
- P = 29.12
- Total volume = 2021.39mm^3

Horizontal fin

- 0.07 wide
  - 1.778mm
  - 1.85mm
- Distance between the center of each rectangle = .28 in
- .17 in tall
  - 4.318mm
  - 4.31mm
- 11 fins total
- Length A/P
  - .51 - 12.954mm
    - .04 / 1.16
    - Mm =
  - 1.16 - 29.464mm
    - .08 / 2.47
  - 1.49 - 37.846mm
    - .11 / 3.12
    - 183.93 mm
  - 1.68 - 42.672
    - .12 / 3.5
  - 1.78 - 45.212mm
    - .13 / 3.71
  - 1.82 - 46.228mm
    - .13 / 3.78
- Length mm
  - 12.92
    - 23.86
  - 29.56
    - 54.57
  - 37.73
    - 69.65
  - 42.62
    - 83.62
  - 45.3
    - 78.67
  - 46.15
    - 85.21
- Total volume = 0.1853”
  - .179214”
  - 2936.79mm
  - 3049.146mm

Radial

- 4.31mm tall
- 22.54mm long
- 3.71 wide
- 8.02 in between each fin on the outside
- 10 fins total
- Area 442.6mm^2
  - Perimeter 469.31mm
- Total volume = 1907.606mm^3

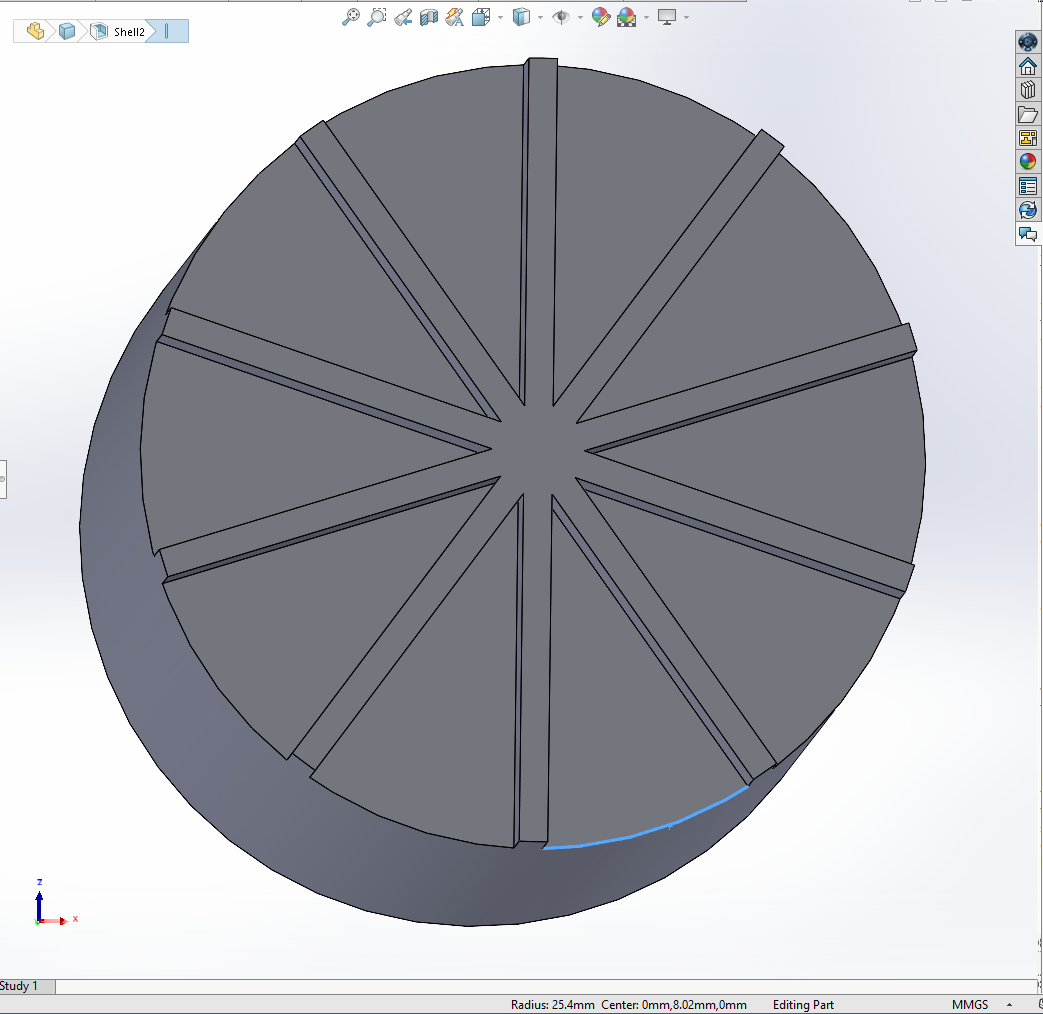
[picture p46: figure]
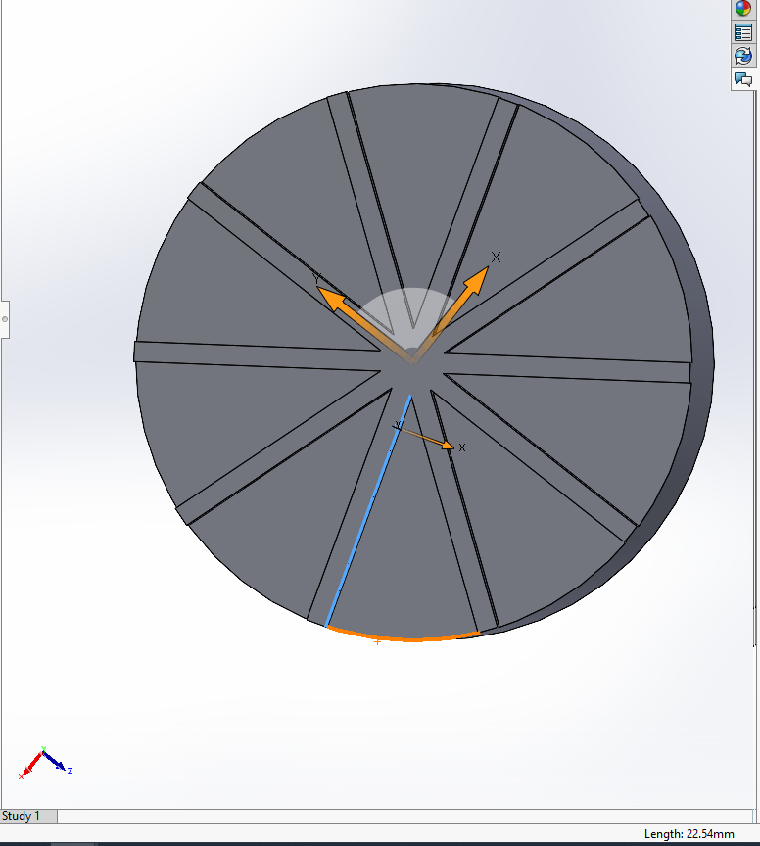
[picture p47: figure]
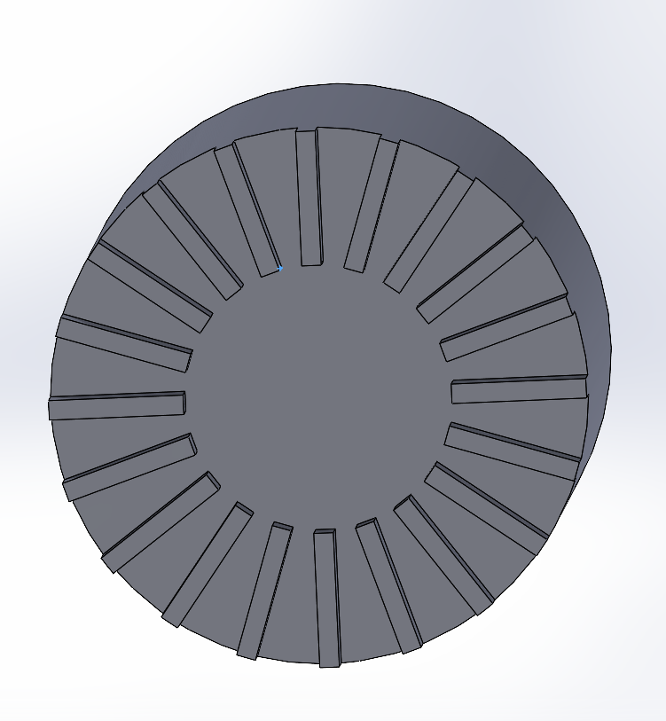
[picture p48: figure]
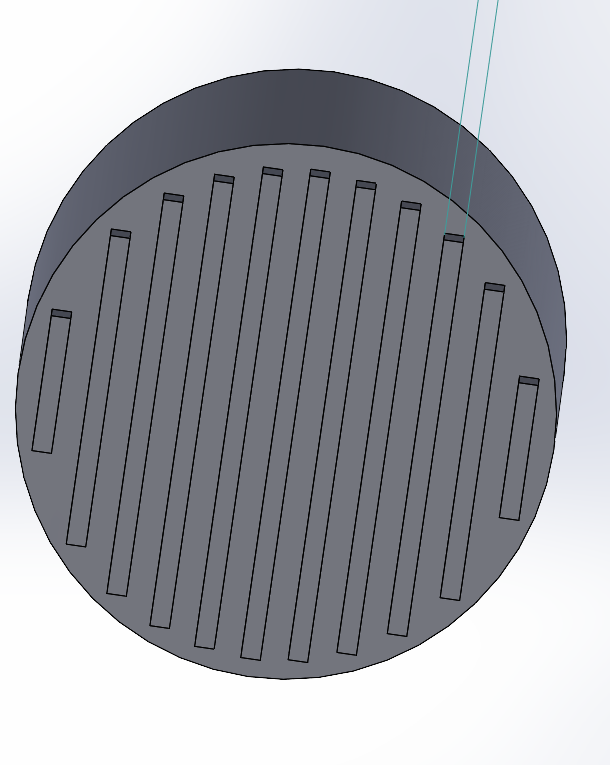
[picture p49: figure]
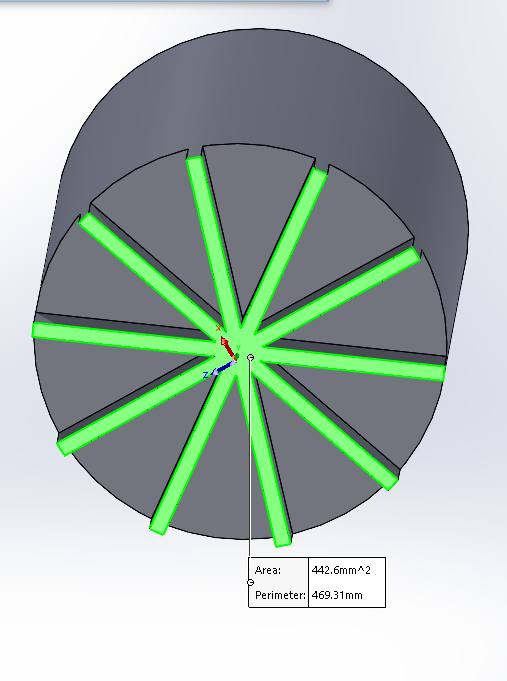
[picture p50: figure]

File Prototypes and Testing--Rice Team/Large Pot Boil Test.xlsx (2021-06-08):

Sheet: Testing Stup
3/16 Boil Test Notch on propane tank labeled 1 L of water

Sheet: Large Pot Testing 46
4/6/2021 TESTING
set-up details
each pot had a corresponding propane tank filled 15lbs
soak pot in cold water for 1 minute between trials
trials ran consecutively for each pot
357 | 257 | 214
 | 100 | 143
 | 0.2801120448 | 0.4005602241
STANDARD
5:57:20 | 357 | 0.7198879552 | 0.2801120448
Trial #1 |  |  | Trial #2 |  | Trial #3 |  | Trial #4
Starting Temp (°C) | 23 |  | Starting Temp | 23.4 | Starting Temp | 23.7 | Starting Temp
Boiling Temp | 97 |  | Boiling Temp | 97.3 | Boiling Temp | 98 | Boiling Temp
Time to Boil | 6:12:00 |  | Time to Boil | 5:28:00 | Time to Boil | 6:12:00 | Time to Boil
 | 372 |  |  | 328 |  | 372
Water Temperature (°C) | Time (Seconds) |  | Water Temperature (°C) | Time (Seconds) | Water Temperature (°C) | Time (Seconds) | Water Temperature (°C) | Time (Seconds)
48 | 60 |  | 41.8 | 60 | 41 | 60 |  | 60
61.6 | 120 |  | 61.8 | 120 | 55 | 120 |  | 120
75 | 180 |  | 76.4 | 180 | 68.3 | 180 |  | 180
85.3 | 240 |  | 87.6 | 240 | 80.5 | 240 |  | 240
90.7 | 300 |  | 94 | 300 | 88 | 300 |  | 300
96 | 360 |  |  | 360 | 93.3 | 360 |  | 360
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

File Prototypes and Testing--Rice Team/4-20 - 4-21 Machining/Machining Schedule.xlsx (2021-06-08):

Time Slot | Person on Shift for Machining with Joe | Person 2 (not required but would be nice)
11:00:00 | Chris
11:30:00 | Chris
12:00:00 | Chris
12:30:00 | Chris
13:00:00 | Chris
13:30:00 | Sam
14:00:00 | Sam
14:30:00 | steph | Sam
15:00:00 | steph | maybe Sana depending on when her 2:30 meeting ends
15:30:00 | Sana
16:00:00 | Sana
16:30:00 | Sana | Chris
17:00:00 | Sana | Chris

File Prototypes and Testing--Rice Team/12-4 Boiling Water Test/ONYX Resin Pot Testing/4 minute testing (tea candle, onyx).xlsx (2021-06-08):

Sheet: Tea Candle Heat Resistant Resin
Pot type | Starting Temperature (°C) | Temperature at 4 minutes (°C) | Difference (°C)
Standard | 19 | 20 | 1
Helical Vane | 19 | 24 | 5
Ribbed | 20 | 22 | 2
Standard (test 2) | 19.8 | 25.4 | 5.6
Bundt | 20.3 | 25.5 | 5.2
Standard with lid | 20.1 | 27.1 | 7
Pot type | Difference (°C)
Standard | 5.6
Helical Vane | 5
Ribbed | 2
Bundt | 5.2
Standard with lid | 7
Pot type | Standard | Helical Vane | Ribbed | Bundt | Standard with lid
Difference (°C) | 5.6 | 5 | 2 | 5.2 | 7

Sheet: Propane Onyx
Pot type | Starting Temperature (°C) | Temperature at 4 minutes (°C) | Difference (°C)
Standard | 21 | 36.2 | 15.2
Ribbed | 21.2 | 44 | 22.8
Bundt | 21.8 | 46.5 | 24.7
Helical Vane | 21.3 | 32.7 | 11.4
Finned Pot | 21.3 | 34.5 | 13.2
Pot type | Difference (°C)
Standard | 15.2
Ribbed | 22.8
Bundt | 24.7
Helical Vane | 11.4
Finned Pot | 13.2
Pot type | Standard | Ribbed | Bundt | Helical Vane | Finned Pot
Difference (°C) | 15.2 | 22.8 | 24.7 | 11.4 | 13.2

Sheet: Resin
Pot type | Starting Temperature (°C) | Temperature at 4 minutes (°C) | Difference (°C)
Standard | 21.8 | 52.1 | 30.3
Ribbed | 21.1 | 38.8 | 17.7
Bundt | 21.4 | 47.8 | 26.4
Helical Vane | 21.3 | 36.8 | 15.5
Finned Pot | - | - | #VALUE!
Pot type | Difference (°C)
Standard | 15.2 | 30.3
Ribbed | 22.8 | 17.7
Bundt | 24.7 | 26.4
Helical Vane | 11.4 | 15.5
Finned Pot | 13.2
Resin
Pot type | Standard | Ribbed | Bundt | Helical Vane | Finned Pot
Difference (°C) | 30.3 | 17.7 | 26.4 | 15.5 | -
Onyx
Pot type | Standard | Ribbed | Bundt | Helical Vane | Finned Pot
Difference (°C) | 15.2 | 22.8 | 24.7 | 11.4 | 13.2
 | Standard | Ribbed | Bundt | Helical Vane
Resin | 30.3 | 17.7 | 26.4 | 15.5
 | Standard | Ribbed | Bundt | Helical Vane
Onyx | 15.2 | 22.8 | 24.7 | 11.4
 | Standard | Helical Vane | Ribbed | Bundt
Tea Candle Onyx | 5.6 | 5 | 2 | 5.2

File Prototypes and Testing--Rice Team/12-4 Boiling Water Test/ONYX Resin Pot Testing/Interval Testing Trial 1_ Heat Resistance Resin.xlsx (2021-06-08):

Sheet: All The Pots
Standard pots | Helical Vane Pot | Bundt Pot | Ribbed Pot
7:01:00 | 14:47:00 | 9:33:00 | 19:22:00

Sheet: Standard Pot
Water Temperature (°C) | Time (Minutes)
21.8 | 0
30.9 | 1
36.7 | 2
45 | 3
52.1 | 4
62.4 | 5
67.5 | 6
 | 7
 | 8
 | 9
 | 10
Final Time to 70°C: | 7:01 minutes

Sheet: Helical Vane
Water Temperature (°C) | Time (Minutes)
21.3 | 0
22.7 | 1
24.6 | 2
31.4 | 3
36.8 | 4
41.5 | 5
45.5 | 6
49.9 | 7
54.4 | 8
58.8 | 9
61.4 | 10
64.9 | 11
67.8 | 12
69.3 | 13
Final Time to 70°C: | 14 min 47 sec

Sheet: Bundt Pot
Water Temperature (°C) | Time (Minutes)
21.4 | 0
27.9 | 1
33.6 | 2
42.6 | 3
47.8 | 4
55.2 | 5
60.7 | 6
64.5 | 7
67.5 | 8
 | 9
 | 10
Final Time to 70°C: | 9 min 33 sec

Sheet: Ribbed Pot
Water Temperature (°C) | Time (Minutes)
21.1 | 0
23.9 | 1
29.9 | 2
34.3 | 3
38.8 | 4
43.5 | 5
47.8 | 6
52 | 7
56.1 | 8
59.1 | 9 | **longer thn 1 min (delay)
61.1 | 10
63.6 | 11
64.5 | 12
65.9 | 13
66.6 | 14
67.6 | 15
68.3 | 16
69.6 | 17
Final Time to 70°C: | 19:22:00

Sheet: Finned Pot
Water Temperature (°C) | Time (Minutes)
 | 0
 | 1
 | 2
 | 3
 | 4
 | 5
 | 6
 | 7
 | 8
 | 9
 | 10
Final Time to 70°C:
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

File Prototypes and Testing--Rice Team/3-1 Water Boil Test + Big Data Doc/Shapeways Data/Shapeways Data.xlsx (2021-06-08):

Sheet: Presentation Data Compilations
 | Avg. time to boil (sec) | (in minutes) | Trial 1 | Trial 2 | Trial 3 | Trial 1 | Trial 2 | Trail 3 | Trial 1 | Trial 2 | Trial 3 | Trial 4 | Trial 1 | Trial 2 | Avg. time | Std. deviation | Pot | Trial 1 | Trial 2 | Trial 3 | Trial 4 | Trial 5 | Trial 6 | Trial 7 | Trial 8 | Trial 9
Radial fins | 290.25 | --> 4 min 50 sec | 240 | 370 | 266 | 231 | 249 | 279 | 292 | 372 | 323 | 405 | 194 | 262 | 290.25 | 64.52642165 | Radial fins | 240 | 370 | 266 | 231 | 249 | 292 | 372 | 323 | 194
Horizontal fins | 270.8888889 | --> 4 min 31 sec | 255 | 293 | 227 | 264 | 204 |  | 318 | 339 | 327 |  | 211 |  | 270.8888889 | 50.96921729 | Horizontal fins | 255 | 293 | 227 | 264 | 204 | 318 | 339 | 327 | 211
Half-radial fins | 235.8 | --> 3 min 56 sec | 210 | 170 | 234 | 227 | 171 |  | 290 | 297 | 294 |  | 171 | 294 | 235.8 | 54.70283356 | Half-radial fins | 210 | 170 | 234 | 227 | 171 | 290 | 297 | 294 | 171
Shapeways pots | Trial 1 | Trial 2 | Trial 3 | Avg. time to boil (sec) | Shapeways pots
Full-Radial fins | 225 | 198 | 240 | 221 | Full-Radial fins
Half-radial fins | 172 | 218 | 197 | 195.6666667 | Half-radial fins
Horizontal fins | 206 | 201 | 222 | 209.6666667 | Horizontal fins
Standard | 252 | 255 | 251 | 252.6666667 | Standard

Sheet: Sheet7
 | Time it took to boil (seconds)
Prototype | Trial 1 | Trial 2 | Trial 3 | Average | SD
Full Radial | 240 | 370 | 266 | 292 | 68.78953409
Half Radial | 210 | 170 | 234 | 204.6666667 | 32.33161507
Horizontal (Parallel) | 255 | 293 | 227 | 258.3333333 | 33.126022
--> std dev | 22.91287847 | 100.8778139 | 20.7926269

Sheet: STANDARD POT #2
Trial #1 |  | Trial #2 |  | Trial #3
Starting Water Temp: | 27.2 | Starting Water Temp: | 32.2 | Starting Water Temp: | 30.9
Height above burner: | 2in ***distance to bottom of the pot (not fins) | Height above burner: | 2in ***distance to bottom of the pot (not fins) | Height above burner: | 2in ***distance to bottom of the pot (not fins)
Amount of water: | 50mL | Amount of water: | 50mL | Amount of water: | 50mL
Water Temperature (°C) | Time (Minutes) | Water Temperature (°C) | Time (Minutes) | Water Temperature (°C) | Time (Minutes)
31.9 | 30 sec | 40.3 | 30 sec | 37.7 | 30 sec
42.1 | 1 | 48.9 | 1 | 47.2 | 1
52.2 | 1.5 | 58.4 | 1.5 | 56.6 | 1.5
63 | 2 | 66.1 | 2 | 66.2 | 2
68.4 | 2min 15 sec | 70.7 | 2min 15 sec | 69.9 | 2min 15 sec
72.9 | 2 min 30 sec | 73.3 | 2 min 30 sec | 74.7 | 2 min 30 sec
76.3 | 2min 45 sec | 77.8 | 2min 45 sec | 77.9 | 2min 45 sec
80.4 | 3 | 80.9 | 3 | 82.1 | 3
85.5 | 3 min 15 sec | 85.3 | 3 min 15 sec | 87.2 | 3 min 15 sec
89.9 | 3.5 | 90.1 | 3.5 | 89.9 | 3.5
94,0 | 3 min 45 sec | 93.8 | 3 min 45 sec | 94.3 | 3 min 45 sec
97.8 | 4 min | 97 | 4 min | 97.8 | 4 min
 | 4 min 15 sec |  | 4 min 15 sec |  | 4 min 15 sec
 | 4.5 |  | 4.5 |  | 4.5
 | 4 min 45sec |  | 4 min 45sec |  | 4 min 45sec
 | 5 min |  | 5 min |  | 5 min
 | 5 min 15 |  | 5 min 15 |  | 5 min 15
 | 5 min 30 |  | 5 min 30 |  | 5 min 30
 | 5 min 45 |  | 5 min 45 |  | 5 min 45
 | 6 min |  | 6 min |  | 6 min
 | 6 min 15 |  | 6 min 15 |  | 6 min 15
 | 6 min 30 |  | 6 min 30 |  | 6 min 30
 | 6 min 45 |  | 6 min 45 |  | 6 min 45
 | 7 min |  | 7 min |  | 7 min
 | 7 min 15 sec |  | 7 min 15 sec |  | 7 min 15 sec
 | 7 min 30 sec |  | 7 min 30 sec |  | 7 min 30 sec
 | 7 min 45 sec |  | 7 min 45 sec |  | 7 min 45 sec
 | 8 |  | 8 |  | 8
 | 8 min 15 sec |  | 8 min 15 sec |  | 8 min 15 sec
 | 8 min 30 sec |  | 8 min 30 sec |  | 8 min 30 sec
 | 8 min 45 sec |  | 8 min 45 sec |  | 8 min 45 sec
 | 9min |  | 9min |  | 9min
Final Time | 4:12:00 | Final Time | 4:15:00 | Final Time | 4:11:00
Final Temp | 99.3 | Final Temp | 99.2 | Final Temp | 99.5
Final time (seconds) | 252 | Final time (seconds) | 255 | Final time (seconds) | 251
Notes: | switched to green tank | Notes: |  | Notes:

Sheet: FULL RADIAL #2
3/16/2021 USES THE GREEN PROPANE TANK
Trial #1 |  | Trial #2 |  | Trial #3
Starting Water Temp: | 30.6 | Starting Water Temp: | 28.8 | Starting Water Temp: | 30.5
Height above burner: | 2in ***distance to bottom of the pot (not fins) | Height above burner: | 2in ***distance to bottom of the pot (not fins) | Height above burner: | 2in ***distance to bottom of the pot (not fins)
Amount of water: | 50mL | Amount of water: | 50mL | Amount of water: | 50mL
Water Temperature (°C) | Time (Minutes) | Water Temperature (°C) | Time (Minutes) | Water Temperature (°C) | Time (Minutes)
38.7 | 30 sec | 35.9 | 30 sec | 38.7 | 30 sec
51.9 | 1 | 49.3 | 1 | 48.8 | 1
63.3 | 1.5 | 60.5 | 1.5 | 57.7 | 1.5
70.5 | 2 | 73 | 2 | 67 | 2
74.6 | 2min 15 sec | 78.3 | 2min 15 sec | 72.8 | 2min 15 sec
78.6 | 2 min 30 sec | 82.5 | 2 min 30 sec | 79 | 2 min 30 sec
84.3 | 2min 45 sec | 88.5 | 2min 45 sec | 88.9 | 2min 45 sec
86.9 | 3 | 93.6 | 3 | 85.9 | 3
91.8 | 3 min 15 sec | 98.9 | 3 min 15 sec | 88.9 | 3 min 15 sec
96 | 3.5 |  | 3.5 | 92.5 | 3.5
99.4 | 3 min 45 sec |  | 3 min 45 sec | 95.9 | 3 min 45 sec
 | 4 min |  | 4 min |  | 4 min
 | 4 min 15 sec |  | 4 min 15 sec |  | 4 min 15 sec
 | 4.5 |  | 4.5 |  | 4.5
 | 4 min 45sec |  | 4 min 45sec |  | 4 min 45sec
 | 5 min |  | 5 min |  | 5 min
 | 5 min 15 |  | 5 min 15 |  | 5 min 15
 | 5 min 30 |  | 5 min 30 |  | 5 min 30
 | 5 min 45 |  | 5 min 45 |  | 5 min 45
 | 6 min |  | 6 min |  | 6 min
 | 6 min 15 |  | 6 min 15 |  | 6 min 15
 | 6 min 30 |  | 6 min 30 |  | 6 min 30
 | 6 min 45 |  | 6 min 45 |  | 6 min 45
 | 7 min |  | 7 min |  | 7 min
 | 7 min 15 sec |  | 7 min 15 sec |  | 7 min 15 sec
 | 7 min 30 sec |  | 7 min 30 sec |  | 7 min 30 sec
 | 7 min 45 sec |  | 7 min 45 sec |  | 7 min 45 sec
 | 8 |  | 8 |  | 8
 | 8 min 15 sec |  | 8 min 15 sec |  | 8 min 15 sec
 | 8 min 30 sec |  | 8 min 30 sec |  | 8 min 30 sec
 | 8 min 45 sec |  | 8 min 45 sec |  | 8 min 45 sec
 | 9min |  | 9min |  | 9min
Final Time | 3:45:00 | Final Time | 3:18:00 | Final Time | 4:00:00
Final Temp | 99.4 | Final Temp | 99.7 | Final Temp | 99.2
Final time (seconds) | 225 | Final time (seconds) | 198 | Final time (seconds) | 240
Notes: |  | Notes: |  | Notes:

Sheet: HALF RADIAL #2
3/16/2021 USED GREEN PROPANE
Trial #1 |  | Trial #2 |  | Trial #3
Starting Water Temp: | 30.5 | Starting Water Temp: | 30.7 | Starting Water Temp: | 32.6
Height above burner: | 2in ***distance to bottom of the pot (not fins) | Height above burner: | 2in ***distance to bottom of the pot (not fins) | Height above burner: | 2in ***distance to bottom of the pot (not fins)
Amount of water: | 50mL | Amount of water: | 50mL | Amount of water: | 50mL
Water Temperature (°C) | Time (Minutes) | Water Temperature (°C) | Time (Minutes) | Water Temperature (°C) | Time (Minutes)
39.8 | 30 sec | 39.4 | 0.5 |  | 30 sec
57.8 | 1 | 48.7 | 1 | 54.6 | 1
67.8 | 1.5 | 62.2 | 1.5 | 67.9 | 1.5
78.6 | 2 | 71.4 | 2 | 77.7 | 2
86 | 2min 15 sec | 76.1 | 2.25 | 82.6 | 2min 15 sec
91.8 | 2 min 30 sec | 81.6 | 2.5 | 86 | 2 min 30 sec
97.5 | 2min 45 sec | 84.5 | 2.75 | 91.1 | 2min 45 sec
 | 3 | 87.8 | 3 | 93.6 | 3
 | 3 min 15 sec | 93.1 | 3.25 | 98.8 | 3 min 15 sec
 | 3.5 | 97.6 | 3.5 |  | 3.5
 | 3 min 45 sec |  | 3 min 45 sec |  | 3 min 45 sec
 | 4 min |  | 4 min |  | 4 min
 | 4 min 15 sec |  | 4 min 15 sec |  | 4 min 15 sec
 | 4.5 |  | 4.5 |  | 4.5
 | 4 min 45sec |  | 4 min 45sec |  | 4 min 45sec
 | 5 min |  | 5 min |  | 5 min
 | 5 min 15 |  | 5 min 15 |  | 5 min 15
 | 5 min 30 |  | 5 min 30 |  | 5 min 30
 | 5 min 45 |  | 5 min 45 |  | 5 min 45
 | 6 min |  | 6 min |  | 6 min
 | 6 min 15 |  | 6 min 15 |  | 6 min 15
 | 6 min 30 |  | 6 min 30 |  | 6 min 30
 | 6 min 45 |  | 6 min 45 |  | 6 min 45
 | 7 min |  | 7 min |  | 7 min
 | 7 min 15 sec |  | 7 min 15 sec |  | 7 min 15 sec
 | 7 min 30 sec |  | 7 min 30 sec |  | 7 min 30 sec
 | 7 min 45 sec |  | 7 min 45 sec |  | 7 min 45 sec
 | 8 |  | 8 |  | 8
 | 8 min 15 sec |  | 8 min 15 sec |  | 8 min 15 sec
 | 8 min 30 sec |  | 8 min 30 sec |  | 8 min 30 sec
 | 8 min 45 sec |  | 8 min 45 sec |  | 8 min 45 sec
 | 9min |  | 9min |  | 9min
Final Time | 2:52:00 | Final Time | 3:38:00 | Final Time | 3:17:00
Final Temp | 99.4 | Final Temp | 99.3 | Final Temp | 99.8
Final time (seconds) | 172 | Final time (seconds) | 218 | Final time (seconds) | 197
Notes: | switched to green tank | Notes: |  | Notes:

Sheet: HORIZONTAL #2
3/16/2021 USED GREEN PROPANE TANK
Trial #1 |  | ~~Trial #2~~ |  | Trial #3 |  | Trial #4
Starting Water Temp: | 30.3 | Starting Water Temp: | 28.9 | Starting Water Temp: | 30.6 | Starting Water Temp: | 30.2
Height above burner: | 2in ***distance to bottom of the pot (not fins) | Height above burner: | 2in ***distance to bottom of the pot (not fins) | Height above burner: | 2in ***distance to bottom of the pot (not fins) | Height above burner: | 2in ***distance to bottom of the pot (not fins)
Amount of water: | 50mL | Amount of water: | 50mL | Amount of water: | 50mL | Amount of water: | 50mL
Water Temperature (°C) | Time (Minutes) | Water Temperature (°C) | Time (Minutes) | Water Temperature (°C) | Time (Minutes) | Water Temperature (°C) | Time (Minutes)
38.8 | 30 sec | 34.5 | 30 sec | 38.8 | 30 sec | 37.1 | 30 sec
47.5 | 1 | 44.6 | 1 | 50.5 | 1 | 47.4 | 1
59.6 | 1.5 | 55.3 | 1.5 | 60.3 | 1.5 | 58.8 | 1.5
71.2 | 2 | 63.8 | 2 | 72.6 | 2 | 68.8 | 2
75.9 | 2min 15 sec | 70.2 | 2min 15 sec | 78.9 | 2min 15 sec | 75.4 | 2min 15 sec
81.8 | 2 min 30 sec | 74.3 | 2 min 30 sec | 82.6 | 2 min 30 sec | 78.6 | 2 min 30 sec
85.9 | 2min 45 sec | 78.6 | 2min 45 sec | 87.3 | 2min 45 sec | 83.2 | 2min 45 sec
90.6 | 3 | 83.8 | 3 | 93.4 | 3 | 88 | 3
97 | 3 min 15 sec | 87 | 3 min 15 sec | 98.4 | 3 min 15 sec | 92.2 | 3 min 15 sec
 | 3.5 |  | 3.5 |  | 3.5 | 97.1 | 3.5
 | 3 min 45 sec |  | 3 min 45 sec |  | 3 min 45 sec |  | 3 min 45 sec
 | 4 min |  | 4 min |  | 4 min |  | 4 min
 | 4 min 15 sec |  | 4 min 15 sec |  | 4 min 15 sec |  | 4 min 15 sec
 | 4.5 |  | 4.5 |  | 4.5 |  | 4.5
 | 4 min 45sec |  | 4 min 45sec |  | 4 min 45sec |  | 4 min 45sec
 | 5 min |  | 5 min |  | 5 min |  | 5 min
 | 5 min 15 |  | 5 min 15 |  | 5 min 15 |  | 5 min 15
 | 5 min 30 |  | 5 min 30 |  | 5 min 30 |  | 5 min 30
 | 5 min 45 |  | 5 min 45 |  | 5 min 45 |  | 5 min 45
 | 6 min |  | 6 min |  | 6 min |  | 6 min
 | 6 min 15 |  | 6 min 15 |  | 6 min 15 |  | 6 min 15
 | 6 min 30 |  | 6 min 30 |  | 6 min 30 |  | 6 min 30
 | 6 min 45 |  | 6 min 45 |  | 6 min 45 |  | 6 min 45
 | 7 min |  | 7 min |  | 7 min |  | 7 min
 | 7 min 15 sec |  | 7 min 15 sec |  | 7 min 15 sec |  | 7 min 15 sec
 | 7 min 30 sec |  | 7 min 30 sec |  | 7 min 30 sec |  | 7 min 30 sec
 | 7 min 45 sec |  | 7 min 45 sec |  | 7 min 45 sec |  | 7 min 45 sec
 | 8 |  | 8 |  | 8 |  | 8
 | 8 min 15 sec |  | 8 min 15 sec |  | 8 min 15 sec |  | 8 min 15 sec
 | 8 min 30 sec |  | 8 min 30 sec |  | 8 min 30 sec |  | 8 min 30 sec
 | 8 min 45 sec |  | 8 min 45 sec |  | 8 min 45 sec |  | 8 min 45 sec
 | 9min |  | 9min |  | 9min |  | 9min
Final Time | 3:26:00 | Final Time |  | Final Time | 3:21:00 | Final Time | 3:42:00
Final Temp | 99.3 | Final Temp |  | Final Temp | 99.6 | Final Temp | 99.3
FInal time (seconds) | 206 | FInal time (seconds) |  | FInal time (seconds) | 201 | FInal time (seconds) | 222
Notes: | switched to green tank | Notes: | POT FELL | Notes: |  | Notes:
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

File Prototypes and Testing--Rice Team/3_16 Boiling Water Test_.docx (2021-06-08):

- Preliminary test (w control pot) - 1 liter of water
  - So smelly oh god
  - About ~6.5 minutes
  - Discussed what a rolling boil looks like

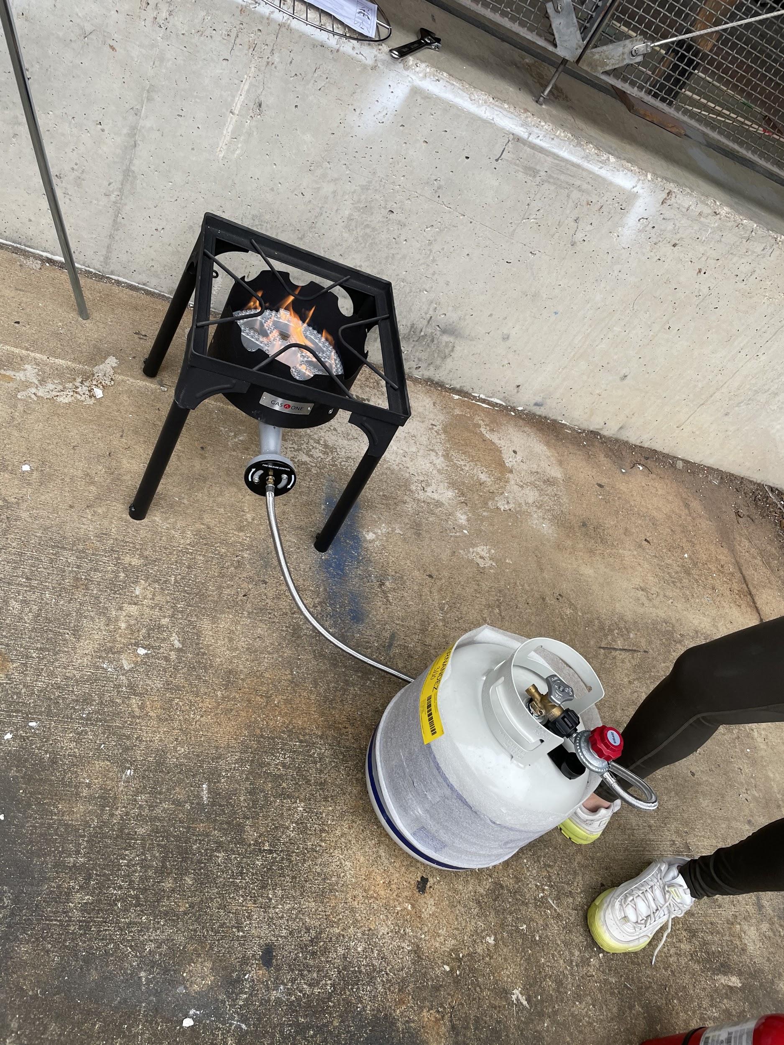
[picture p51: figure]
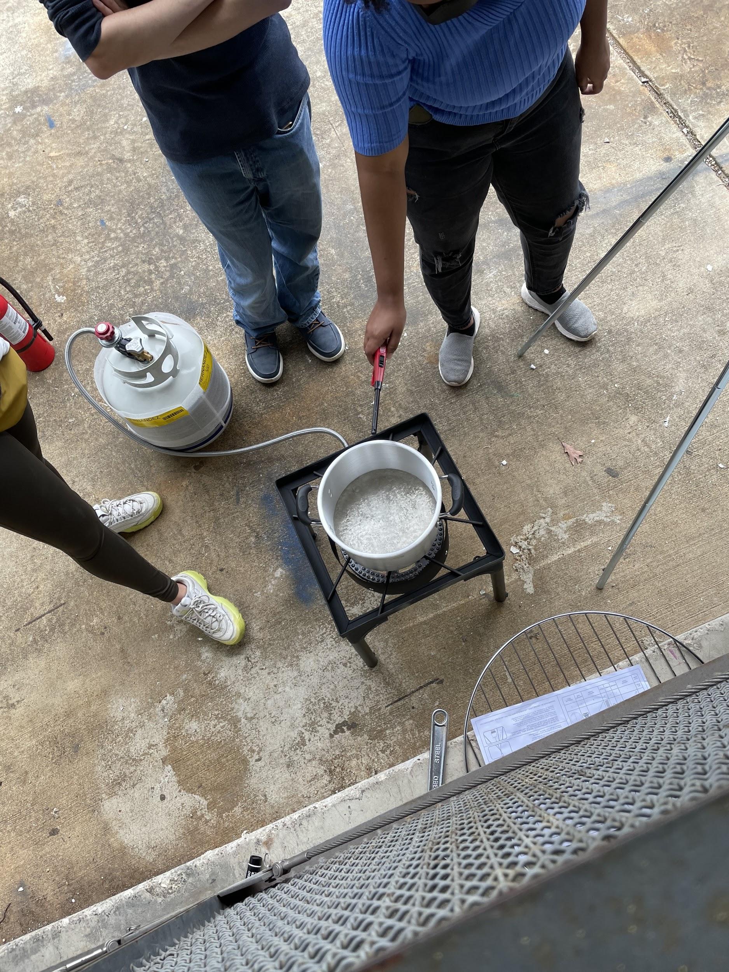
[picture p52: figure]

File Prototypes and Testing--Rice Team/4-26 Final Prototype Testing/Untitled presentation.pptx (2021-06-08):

## Meeting with Rob Updates

## Maching

## Testing the Machined Fins (https://docs.google.com/spreadsheets/d/1SCkbHu5iwDAF7EQHVEYauKBhOfzXvC6huZNwEFWJiQs/edit#gid=0)

## Open Fire Tests (https://docs.google.com/spreadsheets/d/1SCkbHu5iwDAF7EQHVEYauKBhOfzXvC6huZNwEFWJiQs/edit)

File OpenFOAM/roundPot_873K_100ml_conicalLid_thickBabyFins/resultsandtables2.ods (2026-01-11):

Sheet: resultsandtables
N | Time | avg(T) | avg(T_avg) | avg(U (0)) | avg(U (1)) | avg(U (2)) | avg(U (Magnitude)) | avg(Volume) | avg(alphat) | avg(k) | avg(nut) | avg(omega) | avg(p) | avg(p_rgh) | avg(rho) | avg(vtkOriginalCellIds) | max(T) | max(T_avg) | max(U (0)) | max(U (1)) | max(U (2)) | max(U (Magnitude)) | max(Volume) | max(alphat) | max(k) | max(nut) | max(omega) | max(p) | max(p_rgh) | max(rho) | max(vtkOriginalCellIds) | med(T) | med(T_avg) | med(U (0)) | med(U (1)) | med(U (2)) | med(U (Magnitude)) | med(Volume) | med(alphat) | med(k) | med(nut) | med(omega) | med(p) | med(p_rgh) | med(rho) | med(vtkOriginalCellIds) | min(T) | min(T_avg) | min(U (0)) | min(U (1)) | min(U (2)) | min(U (Magnitude)) | min(Volume) | min(alphat) | min(k) | min(nut) | min(omega) | min(p) | min(p_rgh)
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

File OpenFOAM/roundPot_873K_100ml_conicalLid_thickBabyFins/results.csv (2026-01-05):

N | Time | avg(T) | avg(T_avg) | avg(U (0)) | avg(U (1)) | avg(U (2)) | avg(U (Magnitude)) | avg(Volume) | avg(alphat) | avg(k) | avg(nut) | avg(omega) | avg(p) | avg(p_rgh) | avg(rho) | avg(vtkOriginalCellIds) | max(T) | max(T_avg) | max(U (0)) | max(U (1)) | max(U (2)) | max(U (Magnitude)) | max(Volume) | max(alphat) | max(k) | max(nut) | max(omega) | max(p) | max(p_rgh) | max(rho) | max(vtkOriginalCellIds) | med(T) | med(T_avg) | med(U (0)) | med(U (1)) | med(U (2)) | med(U (Magnitude)) | med(Volume) | med(alphat) | med(k) | med(nut) | med(omega) | med(p) | med(p_rgh) | med(rho) | med(vtkOriginalCellIds) | min(T) | min(T_avg) | min(U (0)) | min(U (1)) | min(U (2)) | min(U (Magnitude)) | min(Volume) | min(alphat) | min(k) | min(nut) | min(omega) | min(p) | min(p_rgh)
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

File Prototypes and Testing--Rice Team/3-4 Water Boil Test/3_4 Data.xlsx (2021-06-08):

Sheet: Horizontal Fins
trial 3
time | degrees (C)
initial | 22.1
30 s | 29.2
1 min | 40.3
1 min 30 | 50
2 min | 63.3
2 min 15 |  | readings fluctuated/went down in this range because the thermocouple had been touching the bottom of the pot and we were moving it
2 min 30
2 min 45 | 69.2
3 min | 73.3
3 min 15 | 75.9
3 min 30 | 79
3 min 45 | 82.5
4 min | 85.2
4 min 15 |  | thermocouple turned off zz
4 min 30 | 92
4 min 45 | 93.8
5 min | 95.3
5 min 15 | 97
5 min 30 | 97.6
5 min 45 | 98.8
6 min | 99.2
6:02 rolling boil | 99.4

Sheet: Full Radial Fins
trial 3
time | degrees (C)
initial | 21.5
30 s | 26.3
1 min | 33.1
1 min 30 | 43.6
2 min | 50.3
2 min 15 | 51.2
2 min 30 | 56.9
2 min 45 | 60
3 min | 61.1
3 min 15 | 63.2
3 min 30 | 66.8
3 min 45 | 69.1
4 min | 72
4 min 15 | 73.5
4 min 30 | 75.3
4 min 45 | 77.6
5 min | 78.9
5 min 15 | 80.5
5 min 30 | 82.1
5 min 45 | 83.3
6 min | 84.8
6 min 15 | 85.3
6 min 30 | 87
6 min 45 | 88.5
7 min | 90.5
7 min 15 | 91.5
7 min 30 | 92.5
7 min 45 | 93.8
8 min | 94.3
8 min 15 | 94.9
8 min 30 | 96.2
8 min 45 | 97
9 min | 96.5
9 min 15 | 96.5
9 min 30 | 96.2

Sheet: Half Radial Fins
trial 3
time | degrees (C)
initial | 21.9
30 s
1 min
1 min 30 | 51.8
2 min | 61.3
2 min 15 | 66.3
2 min 30 | 69.4
2 min 45 | 74.3
3 min | 78
3 min 15 | 81.6
3 min 30 | 85.3
3 min 45 | 88.8
4 min | 89.9
4 min 15 | 92.4
4 min 30 | 94.8
4 min 45 | 98
5 min | 99.2
5 min 15
5 min 30
5 min 45
6 min

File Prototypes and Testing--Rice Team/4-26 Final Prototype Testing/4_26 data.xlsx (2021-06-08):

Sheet: Open fire Jet Boil
 | final temperature after 4 minutes]
 | jetboil |  | standard
temperature (C) | initial | final | initial | final
trial 1 | 23 | 87 | 23 | 77.4
trial 2 | 23.1 | 84.3 | 24.8 | 71.2
trial 3 | 24.2 | 100 @ 3:30 | 22.9 | 80.3
Avg temp |  | 67 |  | 52.73333333
performance | 21.29%
temperature Difference(C) | Jetboil | Control |  | Average Max Temperaure in 4 mins | Temperature
trial 1 | 64 | 54.4 |  | Jetboil | 67
trial 2 | 61.2 | 46.4 |  | Control | 52.73333333
trial 3 | 75.8 | 57.4
Average | 67 | 52.73333333
performance | 21.29%

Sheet: propane
ecopot
trial 1 |  | trial 2 |  | trial 3
starting temp (C) | 21.9 | starting temp (C) | 22.7 | starting temp (C) | 24.7
time (s) | temp (C) | time (s) | temp (C) | time (s) | temp (C)
60 | 37.5 | 60 | 37 | 60 | 39
120 | 57 | 120 | 61.2 | 120 | 51.4
180 | 76.3 | 180 | 80 | 180 | 69.1
240 | 95.2 | 240 | 92 | 240 | 81.7
300 |  | 300 |  | 300 | 90.3
360 |  | 360 |  | 360 | 93.5
 |  |  |  |  | did not reach boiling
notes | cracking noise, small warps on bottom | notes |  | notes | this trial is jank
tank: | 1 | tank | 2 | tank | 1
time to boil | 4:12:00 | time to boil | 4:30:00 | time to boil
standard
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

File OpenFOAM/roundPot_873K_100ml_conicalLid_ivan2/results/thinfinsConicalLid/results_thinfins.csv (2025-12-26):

N | Time | avg(T) | avg(T_avg) | avg(U (0)) | avg(U (1)) | avg(U (2)) | avg(U (Magnitude)) | avg(Volume) | avg(alphat) | avg(k) | avg(nut) | avg(omega) | avg(p) | avg(p_rgh) | avg(rho) | avg(vtkOriginalCellIds) | max(T) | max(T_avg) | max(U (0)) | max(U (1)) | max(U (2)) | max(U (Magnitude)) | max(Volume) | max(alphat) | max(k) | max(nut) | max(omega) | max(p) | max(p_rgh) | max(rho) | max(vtkOriginalCellIds) | med(T) | med(T_avg) | med(U (0)) | med(U (1)) | med(U (2)) | med(U (Magnitude)) | med(Volume) | med(alphat) | med(k) | med(nut) | med(omega) | med(p) | med(p_rgh) | med(rho) | med(vtkOriginalCellIds) | min(T) | min(T_avg) | min(U (0)) | min(U (1)) | min(U (2)) | min(U (Magnitude)) | min(Volume) | min(alphat) | min(k) | min(nut) | min(omega) | min(p) | min(p_rgh)
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

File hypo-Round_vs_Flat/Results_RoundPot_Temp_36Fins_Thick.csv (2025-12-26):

Time | avg(T)
0.5 | 298
1 | 298.02
1.5 | 298.03
2 | 298.05
2.5 | 298.08
3 | 298.11
3.5 | 298.14
4 | 298.18
4.5 | 298.22
5 | 298.26
5.5 | 298.31
6 | 298.35
6.5 | 298.4
7 | 298.45
7.5 | 298.51
8 | 298.56
8.5 | 298.62
9 | 298.68
9.5 | 298.74
10 | 298.81
10.5 | 298.88
11 | 298.95
11.5 | 299.03
12 | 299.1
12.5 | 299.19
13 | 299.27
13.5 | 299.36
14 | 299.45
14.5 | 299.55
15 | 299.64
15.5 | 299.74
16 | 299.84
16.5 | 299.95
17 | 300.05
17.5 | 300.16
18 | 300.27
18.5 | 300.39
19 | 300.5
19.5 | 300.62
20 | 300.74
20.5 | 300.86
21 | 300.99
21.5 | 301.12
22 | 301.24
22.5 | 301.37
23 | 301.5
23.5 | 301.63
24 | 301.76
24.5 | 301.9
25 | 302.03
25.5 | 302.16
26 | 302.3
26.5 | 302.43
27 | 302.57
27.5 | 302.71
28 | 302.84
28.5 | 302.98
29 | 303.12
29.5 | 303.27
30 | 303.41
30.5 | 303.55
31 | 303.69
31.5 | 303.83
32 | 303.97
32.5 | 304.12
33 | 304.26
33.5 | 304.41
34 | 304.55
34.5 | 304.7
35 | 304.84
35.5 | 304.99
36 | 305.14
36.5 | 305.29
37 | 305.44
37.5 | 305.59
38 | 305.74
38.5 | 305.88
39 | 306.03
39.5 | 306.18
40 | 306.33
40.5 | 306.48
41 | 306.63
41.5 | 306.78
42 | 306.93
42.5 | 307.08
43 | 307.23
43.5 | 307.38
44 | 307.53
44.5 | 307.68
45 | 307.83
45.5 | 307.98
46 | 308.13
46.5 | 308.28
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

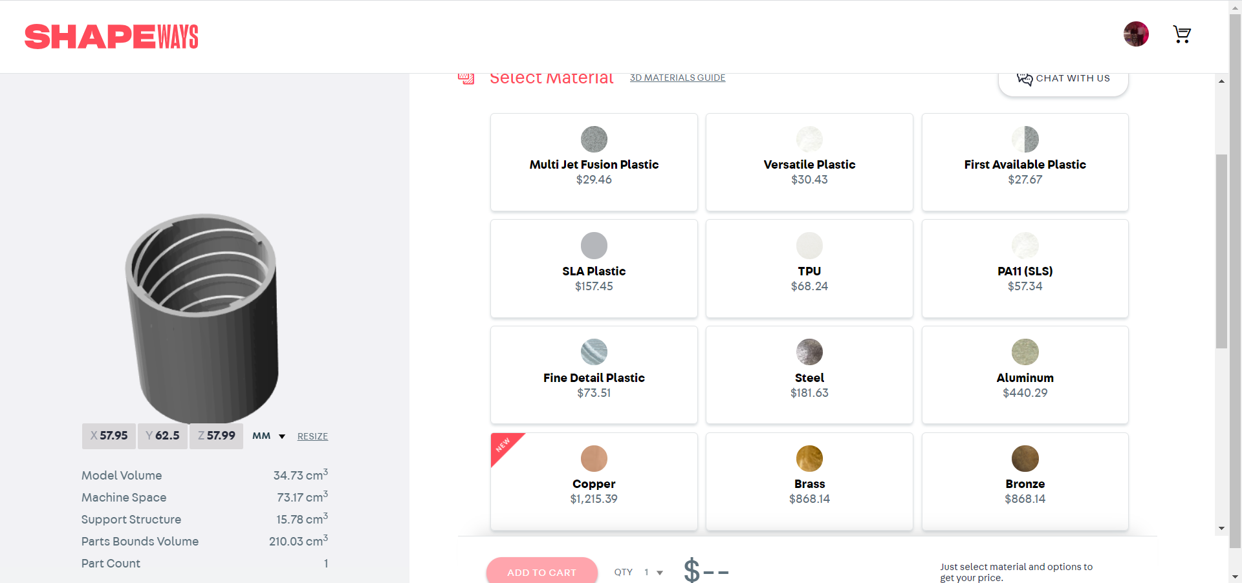
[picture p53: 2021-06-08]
Prototypes and Testing--Rice Team/Shapeways/Outer pot pricing half size.PNG

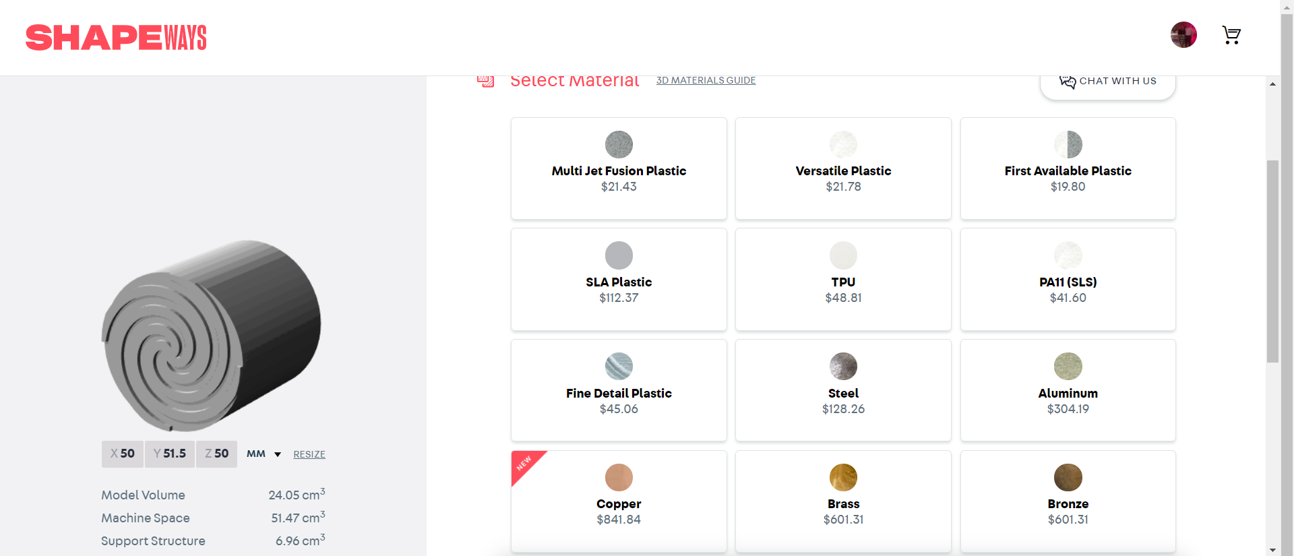
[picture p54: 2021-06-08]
Prototypes and Testing--Rice Team/Shapeways/Inner Pot half size.PNG

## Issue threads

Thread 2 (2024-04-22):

Design a Lid (make it simpler for now.)

RobertLRead, 2024-04-22:
Lid should be tight fitting (maybe 0.2 mm inside the lip of the pot). Tolerance unknown, make it a parmeter.

What is a typical Ghanian pot lid style?

Do Ghanians use oven mitts?

Cledito-Delta, 2024-04-29:
I have made a simple lid common to some locally made Ghanaian pots but I have not completed it with a handle yet

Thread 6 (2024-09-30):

Rob can't run icoFoam in hotfluidheater....

RobertLRead, 2024-09-30:
ubuntu@openfoam2:~/EcoPot/OpenFOAM/hotfluidheater$ icoFoam
/*---------------------------------------------------------------------------*\
| =========                 |                                                 |
| \\      /  F ield         | OpenFOAM: The Open Source CFD Toolbox           |
|  \\    /   O peration     | Version:  v2012                                 |
|   \\  /    A nd           | Website:  www.openfoam.com                      |
|    \\/     M anipulation  |                                                 |
\*---------------------------------------------------------------------------*/
Build  : _b12839ff-20220610 OPENFOAM=2012 patch=220610
Arch   : "LSB;label=32;scalar=64"
Exec   : icoFoam
Date   : Sep 30 2024
Time   : 12:01:10
Host   : openfoam2
PID    : 127686
I/O    : uncollated
Case   : /home/ubuntu/EcoPot/OpenFOAM/hotfluidheater
nProcs : 1
trapFpe: Floating point exception trapping enabled (FOAM_SIGFPE).
fileModificationChecking : Monitoring run-time modified files using timeStampMaster (fileModificationSkew 5, maxFileModificationPolls 20)
allowSystemOperations : Allowing user-supplied system call operations

// * * * * * * * * * * * * * * * * * * * * * * * * * * * * * * * * * * * * * //
Create time

Create mesh for time = 0

PISO: Operating solver in PISO mode

Reading transportProperties

--> FOAM FATAL ERROR: (openfoam-2012 patch=220610)
cannot find file "/home/ubuntu/EcoPot/OpenFOAM/hotfluidheater/constant/transportProperties"

    From virtual Foam::autoPtr<Foam::ISstream> Foam::fileOperations::uncollatedFileOperation::readStream(Foam::regIOobject&, const Foam::fileName&, const Foam::word&, bool) const
    in file global/fileOperations/uncollatedFileOperation/uncollatedFileOperation.C at line 547.

FOAM exiting

Cledito-Delta, 2024-09-30:
Please run the Allrun.pre script first
Then run chtMultiRegionFoam afterwards

Thanks

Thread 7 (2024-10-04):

Help on Fixing Error with snappyMultiRegionHeater case

Cledito-Delta, 2024-10-04:
Please help solve the problem with the recently uploaded OpenFOAM case, snappyMultiRegionHeater. The following error comes up after running the Allrun_Modified bash script and then running "chtMultiRegionFoam" in the terminal:

#0  Foam::error::printStack(Foam::Ostream&) at ??:?
#1  Foam::sigFpe::sigHandler(int) at ??:?
#2  ? in /lib/x86_64-linux-gnu/libc.so.6
#3  Foam::heRhoThermo<Foam::rhoReactionThermo, Foam::SpecieMixture<Foam::singleComponentMixture<Foam::constTransport<Foam::species::thermo<Foam::hConstThermo<Foam::perfectGas<Foam::specie> >, Foam::sensibleEnthalpy> > > > >::calculate(Foam::GeometricField<double, Foam::fvPatchField, Foam::volMesh> const&, Foam::GeometricField<double, Foam::fvPatchField, Foam::volMesh>&, Foam::GeometricField<double, Foam::fvPatchField, Foam::volMesh>&, Foam::GeometricField<double, Foam::fvPatchField, Foam::volMesh>&, Foam::GeometricField<double, Foam::fvPatchField, Foam::volMesh>&, Foam::GeometricField<double, Foam::fvPatchField, Foam::volMesh>&, Foam::GeometricField<double, Foam::fvPatchField, Foam::volMesh>&, bool) at ??:?
#4  Foam::rhoReactionThermo::addfvMeshConstructorToTable<Foam::heRhoThermo<Foam::rhoReactionThermo, Foam::SpecieMixture<Foam::singleComponentMixture<Foam::constTransport<Foam::species::thermo<Foam::hConstThermo<Foam::perfectGas<Foam::specie> >, Foam::sensibleEnthalpy> > > > > >::New(Foam::fvMesh const&, Foam::word const&) at ??:?
#5  Foam::autoPtr<Foam::rhoReactionThermo> Foam::basicThermo::New<Foam::rhoReactionThermo>(Foam::fvMesh const&, Foam::word const&) at ??:?
#6  Foam::rhoReactionThermo::New(Foam::fvMesh const&, Foam::word const&) at ??:?
#7  ? at ??:?
#8  ? in /lib/x86_64-linux-gnu/libc.so.6
#9  __libc_start_main in /lib/x86_64-linux-gnu/libc.so.6
#10  ? at ??:?
Floating point exception

The Allrun script is originally from the tutorials.

RobertLRead, 2024-10-04:
I will try to look at this on Sunday.

On Fri, Oct 4, 2024 at 3:03 PM Cledden Obeng-Poku Kwanin <
***@***.***> wrote:

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

--
Robert L. Read, PhD
Twitter: @RobertLeeRead @pubinvention
Public Invention: https://www.pubinv.org
Join Our Mailing list: ***@***.***
YouTube: https://www.youtube.com/channel/UCJQg_dkDY3KTP1ybugYwReg
Medium: ***@***.***

RobertLRead, 2024-10-06:
Looking at this today after considerable trouble getting my machine working, I get exactly the same error. I am not sure how to do it yet.

Cledito-Delta, 2024-10-06:
Thanks Robert for the feedback.
I have realised that the modified Allrun script for some reason is not running the "changeDictionary" application well. I believe it is due to the "for loop" not properly constructed.

It is supposed to run the changeDictionary with the region option for every region in the case. The changeDictionary gives the initial boundary conditions.

I run it manually by myself "changeDictionary -region bottomAir' and it worked. [The other regions are topAir, heater, leftSolid, rightSolid].

Maybe you can help with fixing the for loop
Thanks

RobertLRead, 2024-10-06:
I will comply. I will (slighly) modify the Allrun_modified script to "echo" the foamListRegions environment variable.

At present I do not understand what "runApplication changedDictionary -region $region" is supposed to do---by which, I mean I don't know how that is a correct Linux command to be executed by the shell. But I will study it.  However, now that I have a path to running it, it is tempting to start to attempt to modify it to be more like a fire, or to modify one of the .stls.

Cledito-Delta, 2024-10-06:
The runApplication seems to run the preprocessing commands from blockMesh, surfaceFeatureExtract...
I believe you can best figure it out or write a better code to achieve the same results. (I think the $region was supposed to show the regions but I echoed it and it is empty)

I think you can modify it that way too.
Looking forward to your results.

RobertLRead, 2024-10-06:
"RunApplication" is added to the "PATH" so that it can be run by this command:

`. ${WM_PROJECT_DIR:?}/bin/tools/RunFunctions `

This defines "runApplication", which takes several arguments like "changeDictionary".

It is the case that runs for me:

```
./Allrun_Modified
blockMesh already run on /home/ubuntu/EcoPot/OpenFOAM/snappyMultiRegionHeater: remove log file 'log.blockMesh' to re-run
surfaceFeatureExtract already run on /home/ubuntu/EcoPot/OpenFOAM/snappyMultiRegionHeater: remove log file 'log.surfaceFeatureExtract' to re-run
snappyHexMesh already run on /home/ubuntu/EcoPot/OpenFOAM/snappyMultiRegionHeater: remove log file 'log.snappyHexMesh' to re-run
Restore 0/ from 0.orig/
splitMeshRegions already run on /home/ubuntu/EcoPot/OpenFOAM/snappyMultiRegionHeater: remove log file 'log.splitMeshRegions' to re-run
AAA
bottomAir topAir heater leftSolid rightSolid
BBB
bottomAir
changeDictionary already run on /home/ubuntu/EcoPot/OpenFOAM/snappyMultiRegionHeater: remove log file 'log.changeDictionary' to re-run
BBB
topAir
changeDictionary already run on /home/ubuntu/EcoPot/OpenFOAM/snappyMultiRegionHeater: remove log file 'log.changeDictionary' to re-run
BBB
heater
changeDictionary already run on /home/ubuntu/EcoPot/OpenFOAM/snappyMultiRegionHeater: remove log file 'log.changeDictionary' to re-run
BBB
leftSolid
changeDictionary already run on /home/ubuntu/EcoPot/OpenFOAM/snappyMultiRegionHeater: remove log file 'log.changeDictionary' to re-run
BBB
rightSolid
changeDictionary already run on /home/ubuntu/EcoPot/OpenFOAM/snappyMultiRegionHeater: remove log file 'log.changeDictionary' to re-run

Use paraFoam -touch-all to create files for paraview post-processing

```

Cledito-Delta, 2024-10-06:
Thanks for the insight on that.

I hope you find a way to fix it. In the meantime, I will have to run changeDictionary manually which is no problem.

Thanks

RobertLRead, 2024-10-06:
Note, reading through the tutorial, I found I had to add these steps:

`
./Allrun-serial
foamToVTK –region heater
paraFoam -touch-all
`
which seem to give pretty good results in ParaView for me.

RobertLRead, 2024-10-06:
@Cledito-Delta  --- I am not sure it is broken.  Is there a reason not to run:

```
./Allclean
./Allrun-serial
foamToVTK
paraFoam -touch-all
```
???

Can you try that, and see if it works well for you?

Cledito-Delta, 2024-10-07:
Sure.
I will run it and update you on what happens.

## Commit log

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2021-06-08 adding Rice Team work
    [3_4 Data.xlsx, 4 minute testing (tea candle, onyx).xlsx, 4_26 data.xlsx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]
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2024-04-29 adding a flat pot from Cledden
    [ParameterizedPotDesigns.scad]
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2024-05-06 adding some volume math
    [ParameterizedPotDesigns.scad]
2024-05-07 got aspect ratio working modestly well
    [ParameterizedPotDesigns.scad]
2024-05-10 Add files via upload
    I have saved the file this way to distinguish it from the main one. The changes I have made are designing a conical lid, two foil shaped fins (regular and fish-shaped)
    [ParameterizedPotDesigns_5-10-24.scad]
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2024-09-16 this is an initial commit
    [ParameterizedPotDesigns.scad, ParameterizedPotDesigns_5-10-24.scad]
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2024-09-23 Case files of a flow past a sphere
    [sphere.stl, sphere_convexFeaturePts.obj, sphere_edgeDirections.obj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]
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2024-10-04 Modified case file on snappyHexMesh with solving error
    [geom.stl, geom_edgeDirections.obj, geom_edgeMesh.obj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]
2024-10-04 Modified bash script indicated as Allrun_Modified
    [geom_edgeDirections.obj, geom_edgeMesh.obj, geom_externalEdges.obj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]
2024-10-04 Modified case of snappyMultiRegionHeater
    [geom_edgeDirections.obj, geom_edgeMesh.obj, geom_externalEdges.obj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]
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2025-04-29 Updated ecoPot2 and new uploads
    [air.stl, box.stl, cledden.stl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]
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2025-05-08 Updated with content rendering modules
    [ParameterizedPotDesigns.scad]
2025-05-20 improving the computation of the content shape, still not mathematically correct
    [ParameterizedPotDesigns.scad]
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2025-05-20 fixing undefined 'V' errors
    [ParameterizedPotDesigns.scad]
2025-05-21 some improvements in the rim and lid
    [ParameterizedPotDesigns.scad]
2025-05-21 improving flat lid and flat pot
    [ParameterizedPotDesigns.scad]
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2025-05-28 Rob thinks Ivan's new code is very good and merges it
    [ParameterizedPotDesigns.scad]
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2025-07-09 pots for first comparison case
    [Flat_Bottom_Pot.stl, Rounded_Bottom_Pot.stl]
2025-07-09 OpenSCAD file used for pot comparison case
    [ParameterizedPotDesigns_Cledden_09-07-25.scad]
2025-07-09 minor adjustments to the rounded pot that I ordered in metal
    [ParameterizedPotDesigns_Cledden_09-07-25.RobThinned.3mf, ParameterizedPotDesigns_Cledden_09-07-25.scad]
2025-08-20 Uploaded by Ivan to be run by Cledden
    [air.stl, air_convexFeaturePts.obj, air_edgeDirections.obj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]
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2025-09-29 initial attempt to define a 3-stone fire or something like it.
    [ParameterizedPotDesigns.scad]
2025-09-30 CSV File of Average Temperatures in water region; flat bottom pot
    [Data_FlatPot_Temp.csv]
2025-09-30 CSV File of Average Temperature of Water Region, Round Bottom Pot
    [Data_RoundPot_Temp.csv]
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2025-10-02 adding test apparatus file
    [TestApparatus.3mf]
2025-10-04 Local files were modified
    [air_convexFeaturePts.obj, air_edgeDirections.obj, air_edgeMesh.obj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]
2025-10-10 Simulation with a more realistic flat bottom pot with a wider bottom
    [air.stl, air_fire.stl, box.stl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]
2025-10-10 CSV Data on Temperature Average for Water Region in Wide Base Flat Bottom Pot
    [Data_FlatPot_Temp_WideBase.csv]
2025-10-25 tweaking for three-stone printable test apparatus
    [ParameterizedPotDesigns.scad]
2025-10-29 FlatLid module redesigned
    [ParameterizedPotDesigns.scad]
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2025-10-30 making the flat lid more robust
    [ParameterizedPotDesigns.scad]
2025-11-05 Mesh is coarse. Round bottom pot with inlet air of 873K
    [air.stl, air50.stl, air_fire.stl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]
2025-11-06 Add files via upload
    Conical Lid
    [ParameterizedPotDesigns.scad]
2025-11-16 fixed lid
    [ParameterizedPotDesigns.scad]
2025-11-23 Round bottom pot with conical lid.
    [air.stl, air50.stl, air_convexFeaturePts.obj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]
2025-11-23 Round bottom pot case with no lid.
    [air.stl, air50.stl, air_convexFeaturePts.obj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]
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2025-11-23 fins fixed
    [air_edgeMesh.obj, ecoPotContentNew_edgeMesh.obj, flatLid_edgeMesh.obj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]
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2025-12-10 adding control of thick fins
    [ParameterizedPotDesigns.scad]
2025-12-10 adding in baby (small) fins
    [ParameterizedPotDesigns.scad]
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2025-12-26 Case with 16 8mm thick fins
    [air.stl, air50.stl, air_convexFeaturePts.obj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]
2025-12-26 Case with 36 8mm thick fins
    [air.stl, air50.stl, air_fire.stl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]
2025-12-26 Results of the average Temp of the water region over time for the 16 8mm thick finned round bottom pot
    [Results_RoundPot_Temp_Thick.csv]
2025-12-26 Results of the average Temp of the water region over time for the 36 8mm thick fins
    [Results_RoundPot_Temp_36Fins_Thick.csv]
2025-12-30 Results of the average temperature of the water region for the 16 1mm thin fin round bottom pot
    [Results_RoundPot_Temp_Thin.csv]
2026-01-12 This is an ongoing pot design modelled after the Erlenmeyer flask
    [erlenmeyer_flask_pot_design.scad]
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2026-03-20 Updated version of flatpot with conical lid @ 873K
    [air.stl, air50.stl, air_fire.stl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]
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2026-03-23 adding an attempt to make a wavy pot
    [radial_wavy.scad]
2026-03-24 some improvments in wavy pot getting ready for printing
    [radial_wavy.scad, wavy pot.scad]
2026-03-25 addint the wavy pot design to the ParameterizedPotDesigns.scad
    [ParameterizedPotDesigns.scad, wavy pot.scad]
2026-04-07 Issues regarding volume calculation fixed
    [erlenmeyer_flask_pot_design.scad]
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2026-04-15 Add files via upload
    Completed Erlenmeyer Flask model
    [erlenmeyer_flask_pot_design.scad]
2026-04-15 Add files via upload
    Issues fixed. Model ready for simulation
    [erlenmeyer_flask_pot_design.scad]
2026-04-26 Erlenmeyer Pot simulation with 1.6605mm instead of 1.16605mm wall thickness
    [air.stl, air50.stl, air_convexFeaturePts.obj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]
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2026-05-03 minor bug fix
    [ParameterizedPotDesigns -- updated (april).scad, wavy pot.scad]
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2026-05-12 very major improvements and addition to main file
    [ParameterizedPotDesigns.scad, spherical_updated_code.scad]
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2026-05-12 noting radius is not correct in wavy pot
    [ParameterizedPotDesigns.scad]
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2026-08-05 Add files via upload
    Model used for creating stls to simulate the Wavy Pot
    [ParameterizedPotDesigns_with_wavy.scad]
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
